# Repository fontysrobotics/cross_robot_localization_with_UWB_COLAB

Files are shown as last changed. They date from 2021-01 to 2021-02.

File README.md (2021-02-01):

# cross_robot_localization_with_UWB_COLAB

The new way to design large scale automation project is through the use of Autonomously Guided Vehicles (AGVs). They allow the connection of different workcells to have more flexibility and all this autonomously. This new technology brings a brandd new market with different companies competing to manufacture the best robot for a said application. This brings the costumers to a place where they have to go to different suppliers for the best AGVs based on their application. Incorporating AGVSs of different brands in the same automation process is a difficult task. While AGVs are good at navigating around a building and completing repetitive tasks, when faced with an unknown moving object such as another AGV they get into trouble. As the different brands cannot communicate this creates a serious issue.

## Project

The goal of the project is to make collaboration between AGVs of different brands possible using a relatively cheap solution. The main issue with collaboration is the lack of communication of crucial data. As the issue arises for navigation, the most important data to be shared between the AGVs is location. Localizing multi-vendor AGVs and sharing their location on the same delocalised system. This will allow the recognition of AGVs as obstacles and will leave room for future implementation of a task division control system. This delocalised communication system will achieve collaboration between the AGVs of various brands.

## Problem

The problem of the assignment is to create a delocalised communication system between the AGVs that can determine the position of each AGV. The localization system is built on the decawave UWB device. The principle of this device is to use the delay in Ultra Wide Band signals to measure distance between the devices on the same network. This localization system must be integrated with the AGVs. Each AGV must have a UWB device for localization which in some way has to be connected to a network of all other AGVs. The creation of this system is the problem of the assignment.

## Solution

In order to incorporate the UWB localization system with the AGV, a device titled Communication and Localization Add on Board or CoLAB was created as a solution. The CoLAB device handles the creation and connection of an AGV to the localization network as well as to the UWB network and the AGV. A CoLAB device is attached to each AGV along with two UWB devices that serve as a front and back tag for the positioning. Inside the CoLAb is a Raspberry pi that reads the positioning information from the two tags via UART. This information is processed to return location and orientation. The CoLAB publishes location, orientation and other useful information from the AGV config file as a message to a network which all AGVs are connected to. From this network AGVs scan and read messages of other AGVs and determine their location orientation and most important properties. This information is sent to the AGV and can be implemented for the software to recognize other AGVs as obstacles. Thus, solving the Communication and Localization issue between AGVs of different vendors. This system also opens the possibility to many more future solutions.

## Navigation of gitHub Page

Within the following the contents of the CoLAB gitHub page will be explained. The three main components the read me, repository and wiki will be highlighted.

* ### Read Me 
Within the read me the basic introduction to the project and problem happens. The products of the project thus to content of the gitHub page is also explained. Alongside this information the main credits to the page as well as a quick how to use guide can be found.

* ### Repository
The repository is where the final products of the project thus the content can be found. This is where the final designs and software can be downloaded from. All the research material used is also provided alongside the datasheets and explaining flow charts and diagrams. Some files to aid with system set up can also be found in the repository.

* ### Wiki
The wiki is where the design is given a further explanation. Each components of the system is given a page along with explanations to its design. Some pages elaborate on the system, validation or final conclusions. For navigation use the table of contents side bar on the right side of the page.

## How to use

Within the following a quick start guide will be given on how to set up the CoLAB system on your own AGV. It is Important to note that this guide will give a global layout and reference set up files, however some extra more in depth set up information might be found in the referenced files.

* ### How to initiate (loading code + connect)
In order to set up a system like the CoLAB first order all the components, print the parts and PCB. After this is completed there is a guide titled (start guide) in the depositor that is an assembly guide to the CoLAB. In this guide further information details how to set up a raspberry pi for the CoLAB as well.
Once the CoLAB is set up it is time to set up the UWB devices with the correct image. Only the tags on the AGV have to be set up

* ### How to set up (config)
It is very easy to use a CoLAB device. It is almost plug and play. There are a couple of things that need to be commpleted before use. A list of these can be found below. It is important to note that these steps must be repeated for each CoLAB device on each AGV.

1. Order all parts and assemble the device compoennets using the [guides](https://github.com/fontysrobotics/cross_robot_localization_with_UWB_COLAB/tree/main/PhysicalSystem/Assembly_documents)
1. Fill out [Configuration File](https://github.com/fontysrobotics/cross_robot_localization_with_UWB_COLAB/blob/main/Software/CoLAB_config.py) of AGV
1. Plug tags to CoLAB and Attach to AGV
1. Note down distance between tags in config file
1. Set up ports of tags using [set up guide](https://github.com/fontysrobotics/cross_robot_localization_with_UWB_COLAB/blob/main/UWB_Documentation/UWB_Setup_Guides/Use%20RaspberryPi%20terminal%20(1).docx)
1. The device must be connected to the network and it is ready to use

* ### End results
As an end reslut of running the code correctly, there are two important aspects taht happen. The communication code between all the connected AGVs is running and they are communicating their information to each other. The second thing is a visualziation software that is built into every AGV. This shows the AGVs around. This is the end result of code in a nutshell, the wiki explains further information of the exact communication and information passing through.

## Bibliography & Credits

This project was created as part of a Mechatronics university course for Fontys University of Applied Sciences with the involvement of the following parties:

### Created by
* Nicole Celine
* Arjan van der Heijden
* Mike Luiken
* Simeon Stoyanov
* Pascal Dinjens
* Long Nguyen
* Ryan Muhammad
* Benedek Papp

### Mentorship and Project Ownership
* Pablo Negrete Rubio
* Sjriek Alers

Throughout the project the following sources were used as guidence, inspiration and technical details:

### Sources

* EEAdi, et al. “Using DWM1001 API on Raspberry Pi and PySerial.” Decawave Tech Forum, 8 Dec. 2019, [decaforum.decawave.com/t/using-dwm1001-api-on-raspberry-pi-and-pyserial/6567]( decaforum.decawave.com/t/using-dwm1001-api-on-raspberry-pi-and-pyserial/6567). 

* Robots, Mobile Industrial. “Please Select Language.” MiR100™ | Mobile Industrial Robots, [www.mobile-industrial-robots.com/en/solutions/robots/mir100/]( www.mobile-industrial-robots.com/en/solutions/robots/mir100/). 

* “The Standard for IoT Messaging.” MQTT, [mqtt.org/]( mqtt.org/).

* Eclipse Mosquitto, 8 Jan. 2018, [mosquitto.org/]( mosquitto.org/.). 

* Craggs, Ian. “Eclipse Paho: The Eclipse Foundation.” Enabling Open Innovation & Collaboration, [www.eclipse.org/paho/]( www.eclipse.org/paho/). 

* “Visualization with Python¶.” Matplotlib, [matplotlib.org/]( matplotlib.org/). 

* “Home.” Decawave, 29 May 2019, [decawave.com/](decawave.com/). 

* Apichet Garaipoom I love the electronic circuits. I will collect a lot of circuit electronics to teach my son and are useful for everyone., et al. “LM2596 Circuit Voltage Regulator and LM2673 Datasheet.” ElecCircuit.com, 19 July 2020, [www.eleccircuit.com/regulator-switching-dc-to-dc-step-down-voltage-with-lm2596/]( www.eleccircuit.com/regulator-switching-dc-to-dc-step-down-voltage-with-lm2596/.). 

* “LTC Debuts LTC4060 NiMH/NiCd Battery Charger - New Industry Products.” EEPower, [eepower.com/new-industry-products/ltc-debuts-ltc4060-nimhnicd-battery-charger/#]( eepower.com/new-industry-products/ltc-debuts-ltc4060-nimhnicd-battery-charger/#). 

* “Dual 4A Ideal Diodes with Adjustable Current Limit.” Datasheet, Linear Technology Co., [datasheet.datasheetarchive.com/originals/distributors/Datasheets-SFU1/DSASFU10008413.pdf]( datasheet.datasheetarchive.com/originals/distributors/Datasheets-SFU1/DSASFU10008413.pdf). 

* Zach-Goh. “Zach-Goh/Omron_LD_ROS_Package.” GitHub, [github.com/zach-goh/Omron_LD_ROS_Package](github.com/zach-goh/Omron_LD_ROS_Package). 

* “OMRON Industrial Automation.” OMRON, [www.ia.omron.com/]( www.ia.omron.com/). 

* “BU-203: Nickel-Based Batteries.” Nickel-Based Batteries Information – Battery University, [batteryuniversity.com/learn/article/nickel_based_batteries](batteryuniversity.com/learn/article/nickel_based_batteries).

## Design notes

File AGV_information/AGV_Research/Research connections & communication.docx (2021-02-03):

# Research Connections & Communication

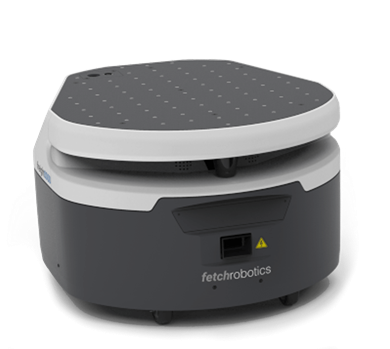
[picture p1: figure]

Fetch Robotics, Freight Base (https://fetchrobotics.com/robotics-platforms/freight-base/)

## Hardware connections wired:

2x USB, 2x Ethernet, RS-45

## Hardware connections wireless:

Wi-Fi: 802.11ABGN and 802.15.1

## Software (operating system):

Ubuntu Linux LTS, Robot Operating System (ROS)

## Control options:

Not specified

# OTTO Motors, OTTO 100 (https://ottomotors.com/amrs)

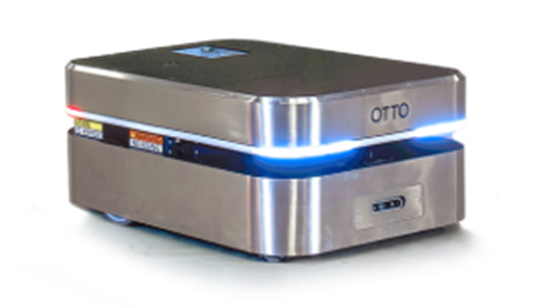
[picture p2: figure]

## Hardware connections wired:

2x USB 3.0, 1x Ethernet POE, 16x DIO, RS-232

## Hardware connections wireless:

Wi-Fi: 802.11ABGNAC, 5 Ghz

## Software (operating system):

Not specified

## Control options:

OTTO Fleet Manager™

OTTO Industrial API

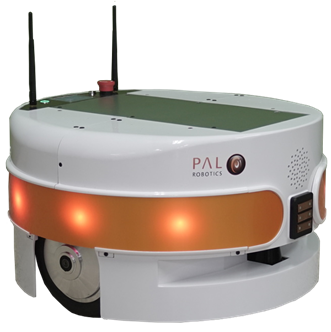
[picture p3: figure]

# PAL Robotics - TIAGo Base (https://pal-robotics.com/robots/tiago-base/)

## Hardware connections wired:

I/O, CAN

## Hardware connections wireless:

Wi-Fi, Bluetooth

## Software (operating system):

Ubuntu LTS, Robot Operating System (ROS) (http://wiki.ros.org/Robots/TIAGo-base)

## Control options:

Web GUI

RESTful API

# Waypoint Robotics, Vector™ (https://waypointrobotics.com/vector-robotic-mobility-platform/)

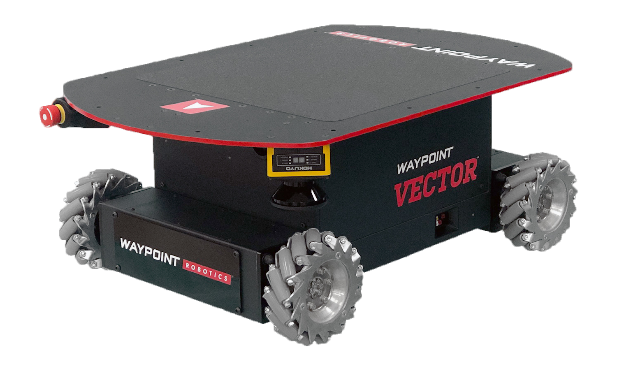
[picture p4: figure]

## Hardware connections wired:

USB, Ethernet

## Hardware connections wireless:

Not specified

## Software (operating system):

Robot Operating System (ROS)

## Control options:

Not specified

## Clearpath, DINGO (https://clearpathrobotics.com/dingo-indoor-mobile-robot/)

## Hardware connections wired:

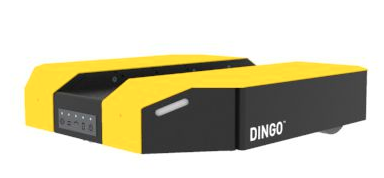
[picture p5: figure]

USB 3.0, Ethernet, RS-232

## Hardware connections wireless:

Not specified

## Software (operating system):

Robot Operating System (ROS)

## Control options:

ROS Kinetic

MoveIt!

ROS ARK API

# Geek+ - M100 (https://www.geekplus.com/product-2/moving)

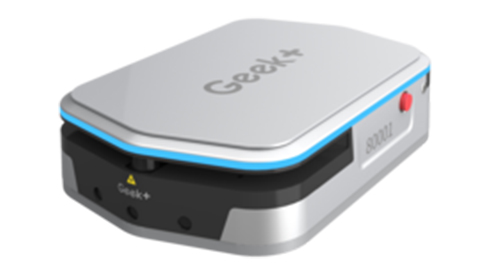
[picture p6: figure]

## Hardware connections wired:

Not specified

## Hardware connections wireless:

Not specified

## Software (operating system):

Not specified

## Control options:

Not specified

Geek+ is only offering complete solutions for warehouse automation. No technical information of the AGVs was found.

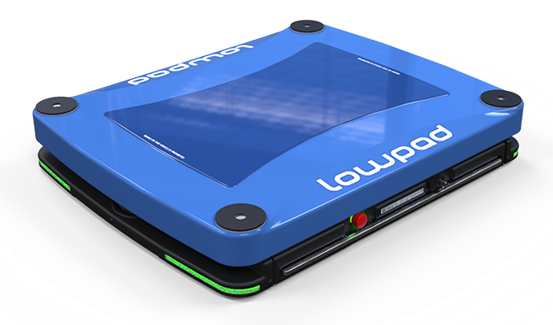
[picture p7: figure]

## Lowpad, M (https://www.lowpad.com/lowpad-family/lowpad-m)

## Hardware connections wired:

?

## Hardware connections wireless:

?

## Software (operating system):

?

## Control options:

?

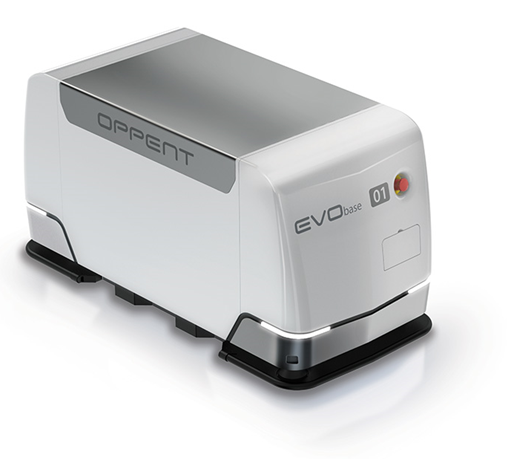
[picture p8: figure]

## Oppent EVO, base™ (https://www.oppent-evo.com/en/prodotto/evo-base-2/)

## Hardware connections wired:

?

## Hardware connections wireless:

?

## Software (operating system):

?

## Control options:

?

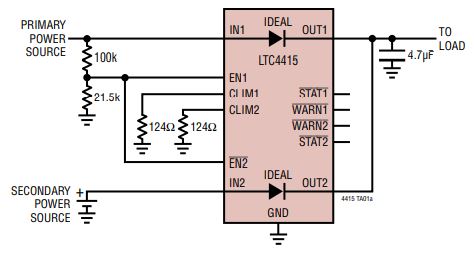
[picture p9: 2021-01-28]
Wiki_Images/LTC4415_Schematic.JPG

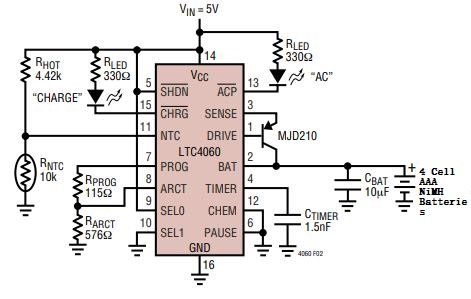
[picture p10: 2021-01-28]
Wiki_Images/LTC4060_Schematic.png

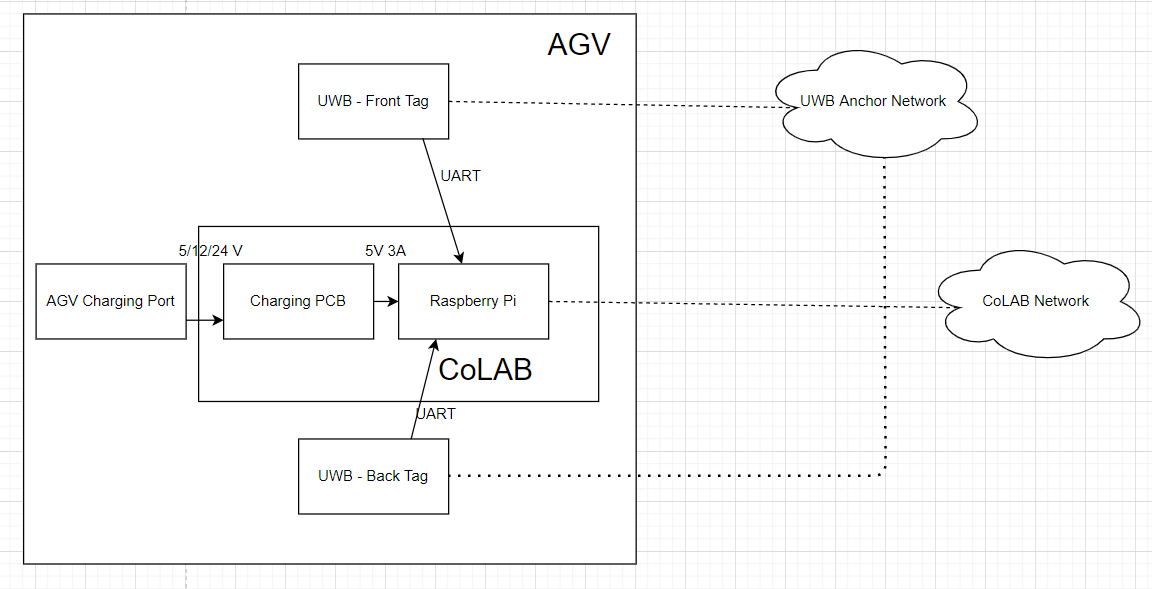
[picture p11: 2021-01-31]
Wiki_Images/System Architecture.PNG

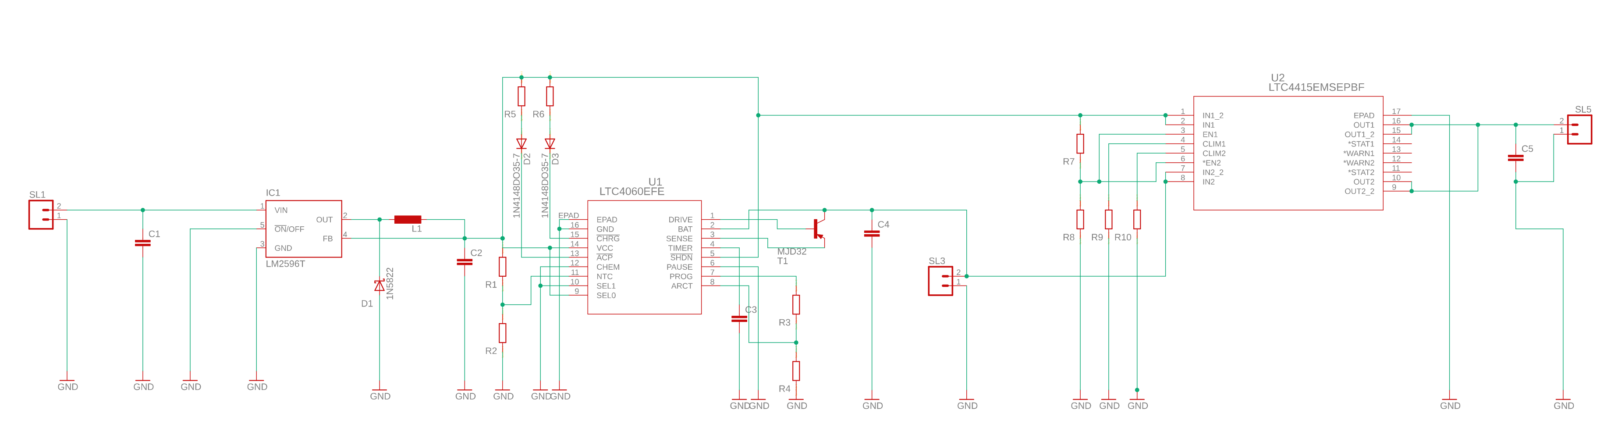
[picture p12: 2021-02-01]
Wiki_Images/MicrosoftTeams-image (1).png

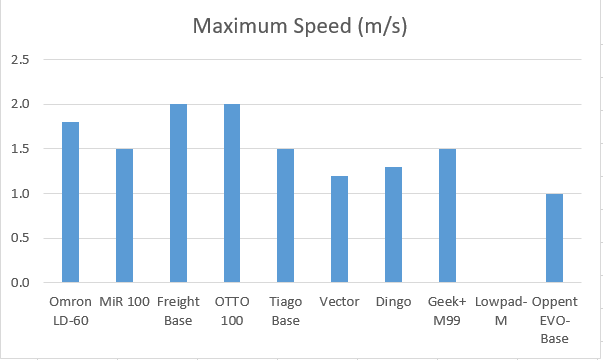
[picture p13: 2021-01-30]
Wiki_Images/AGVinfoMaxSpeed.PNG

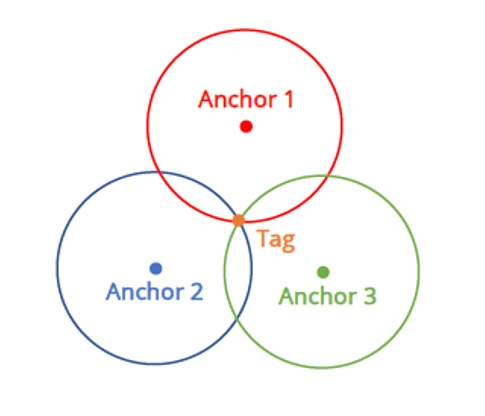
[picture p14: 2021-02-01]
Wiki_Images/pic 2.jpg

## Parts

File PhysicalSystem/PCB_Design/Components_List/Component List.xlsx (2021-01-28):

CoLAB PCB Components List
No. | Components | Description
1 | R NTC (Negative Temperature Components) | 10K
2 | R HOT | 4.42K
3 | R LED | 330
4 | R PROG | 115
5 | R ARCT | 576
6 | MJD210 (PNP) | Complementary Plastic Power Transistor
7 | C TIMER | 1.5nF
8 | C BATTERY | 10µF
9 | LTC4060 | Fast Charging system for NiMH or NiCd batteries
10 | R CLIM1 | 124
11 | R CLIM2 | 124
12 | C OUT (LTC4415) | 4.7µF
13 | R PRIMARY POWER SOURCE (IN 1) | 100K
14 | R PRIMARY POWER SOURCE (EN 1) | 21.5K
15 | LTC4415 | Two monolithic PowerPath ideal diodes
16 | C IN | 680µF
17 | 1N5822 | 3.0 Amps Schottky Barrier Rectifiers
18 | COIL | 33 µH

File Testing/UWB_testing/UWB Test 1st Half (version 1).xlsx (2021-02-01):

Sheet: MiRtest1
Time Stamp | Tag identifier | Column3 | Column4.1.1 | X | Y | Z | Q | Column4.2 | Column5.1 | Column5.2 | Column5.3 | Column5.4 | Column5.5 | Column5.6 | Column5.7 | Column5.8 | Column5.9 | Column5.10 | Column5.11 | Column5.12 | Column5.13 | Column6 | Column7
1602569 | started location data observation of FF | F9 | 57 |  |  |  |  |  | 8C |  |  |  |  |  |  |  |  |  |  |  |  | C7 | 34
1602616 | 0xâ€¦4583 location data | position |  | 1679 | 811 | 220 | 29 | distances |  | 5486 | distance=Distance{length=2941, | 100 | 8397 | distance=Distance{length=8418, | 100 | 0C0C | distance=Distance{length=9623, | 100 | 1B06 | distance=Distance{length=12305, | 100}
1602617 | 0xâ€¦4583 location data | position |  | 1679 | 828 | 231 | 31 | distances |  | 5486 | distance=Distance{length=2941, | 100 | 8397 | distance=Distance{length=8357, | 100 | 0C0C | distance=Distance{length=9543, | 100 | 1B06 | distance=Distance{length=12286, | 100}
1602717 | 0xâ€¦4583 location data | position |  | 1675 | 826 | 230 | 30 | distances |  | 5486 | distance=Distance{length=2922, | 100 | 8397 | distance=Distance{length=8409, | 100 | 0C0C | distance=Distance{length=9599, | 100 | 1B06 | distance=Distance{length=12295, | 100}
1602816 | 0xâ€¦4583 location data | position |  | 1685 | 805 | 235 | 33 | distances |  | 5486 | distance=Distance{length=2913, | 100 | 8397 | distance=Distance{length=8343, | 100 | 0C0C | distance=Distance{length=9674, | 100 | 1B06 | distance=Distance{length=12319, | 100}
1602916 | 0xâ€¦4583 location data | position |  | 1665 | 790 | 241 | 30 | distances |  | 5486 | distance=Distance{length=2857, | 100 | 8397 | distance=Distance{length=8432, | 100 | 0C0C | distance=Distance{length=9656, | 100 | 1B06 | distance=Distance{length=12262, | 100}
1603017 | 0xâ€¦4583 location data | position |  | 1656 | 791 | 232 | 29 | distances |  | 5486 | distance=Distance{length=2908, | 100 | 8397 | distance=Distance{length=8451, | 100 | 0C0C | distance=Distance{length=9623, | 100 | 1B06 | distance=Distance{length=12319, | 100}
1603082 | 0xâ€¦4583 location data | position |  | 1649 | 788 | 242 | 31 | distances |  | 5486 | distance=Distance{length=2866, | 100 | 8397 | distance=Distance{length=8409, | 100 | 0C0C | distance=Distance{length=9623, | 100 | 1B06 | distance=Distance{length=12459, | 100}
1603181 | 0xâ€¦4583 location data | position |  | 1659 | 784 | 234 | 31 | distances |  | 5486 | distance=Distance{length=2951, | 100 | 8397 | distance=Distance{length=8366, | 100 | 0C0C | distance=Distance{length=9656, | 100 | 1B06 | distance=Distance{length=12239, | 100}
1603215 | 0xâ€¦5106 location data | position |  | 2153 | 744 | -138 | 30 | distances |  | 5486 | distance=Distance{length=3489, | 100 | 8397 | distance=Distance{length=8034, | 100 | 0C0C | distance=Distance{length=9848, | 100}
1603234 | started location data observation of D4 | F1 | 18 |  |  |  |  |  | F0 |  |  |  |  |  |  |  |  |  |  |  |  | 24 | 55
1603281 | 0xâ€¦4583 location data | position |  | 1657 | 789 | 223 | 29 | distances |  | 5486 | distance=Distance{length=2951, | 100 | 8397 | distance=Distance{length=8409, | 100 | 0C0C | distance=Distance{length=9623, | 100 | 1B06 | distance=Distance{length=12342, | 100}
1603315 | 0xâ€¦5106 location data | position |  | 2154 | 745 | -138 | 31 | distances |  | 5486 | distance=Distance{length=3489, | 100 | 8397 | distance=Distance{length=8025, | 100 | 0C0C | distance=Distance{length=9857, | 100 | 1B06 | distance=Distance{length=11929, | 100}
1603382 | 0xâ€¦5106 location data | position |  | 2174 | 737 | -125 | 34 | distances |  | 5486 | distance=Distance{length=3489, | 100 | 8397 | distance=Distance{length=7936, | 100 | 0C0C | distance=Distance{length=9895, | 100 | 1B06 | distance=Distance{length=11962, | 100}
1603382 | 0xâ€¦4583 location data | position |  | 1650 | 782 | 228 | 30 | distances |  | 5486 | distance=Distance{length=2866, | 100 | 8397 | distance=Distance{length=8451, | 100 | 0C0C | distance=Distance{length=9642, | 100 | 1B06 | distance=Distance{length=12319, | 100}
1603483 | 0xâ€¦5106 location data | position |  | 2176 | 733 | -116 | 33 | distances |  | 5486 | distance=Distance{length=3461, | 100 | 8397 | distance=Distance{length=7982, | 100 | 0C0C | distance=Distance{length=9876, | 100 | 1B06 | distance=Distance{length=11972, | 100}
1603501 | 0xâ€¦4583 location data | position |  | 1648 | 796 | 225 | 29 | distances |  | 5486 | distance=Distance{length=2955, | 100 | 8397 | distance=Distance{length=8381, | 100 | 0C0C | distance=Distance{length=9590, | 100 | 1B06 | distance=Distance{length=12375, | 100}
1603582 | 0xâ€¦5106 location data | position |  | 2175 | 732 | -113 | 32 | distances |  | 5486 | distance=Distance{length=3471, | 100 | 8397 | distance=Distance{length=7997, | 100 | 0C0C | distance=Distance{length=9871, | 100 | 1B06 | distance=Distance{length=11859, | 100}
1603583 | 0xâ€¦4583 location data | position |  | 1654 | 799 | 206 | 28 | distances |  | 5486 | distance=Distance{length=3002, | 100 | 8397 | distance=Distance{length=8390, | 100 | 0C0C | distance=Distance{length=9637, | 100 | 1B06 | distance=Distance{length=12342, | 100}
1603682 | 0xâ€¦5106 location data | position |  | 2192 | 731 | -103 | 34 | distances |  | 5486 | distance=Distance{length=3489, | 100 | 8397 | distance=Distance{length=7922, | 100 | 0C0C | distance=Distance{length=9881, | 100 | 1B06 | distance=Distance{length=11887, | 100}
1603683 | 0xâ€¦4583 location data | position |  | 1667 | 797 | 177 | 28 | distances |  | 5486 | distance=Distance{length=3044, | 100 | 8397 | distance=Distance{length=8409, | 100 | 0C0C | distance=Distance{length=9665, | 100 | 1B06 | distance=Distance{length=12286, | 100}
1603782 | 0xâ€¦5106 location data | position |  | 2190 | 723 | -106 | 32 | distances |  | 5486 | distance=Distance{length=3480, | 100 | 8397 | distance=Distance{length=7987, | 100 | 0C0C | distance=Distance{length=9904, | 100 | 1B06 | distance=Distance{length=11901, | 100}
1603799 | 0xâ€¦4583 location data | position |  | 1664 | 809 | 211 | 32 | distances |  | 5486 | distance=Distance{length=2880, | 100 | 8397 | distance=Distance{length=8362, | 100 | 0C0C | distance=Distance{length=9557, | 100 | 1B06 | distance=Distance{length=12305, | 100}
1603881 | 0xâ€¦5106 location data | position |  | 2188 | 718 | -108 | 32 | distances |  | 5486 | distance=Distance{length=3475, | 100 | 8397 | distance=Distance{length=7992, | 100 | 0C0C | distance=Distance{length=9900, | 100 | 1B06 | distance=Distance{length=11840, | 100}
1603882 | 0xâ€¦4583 location data | position |  | 1660 | 821 | 192 | 27 | distances |  | 5486 | distance=Distance{length=3012, | 100 | 8397 | distance=Distance{length=8423, | 100 | 0C0C | distance=Distance{length=9590, | 100 | 1B06 | distance=Distance{length=12328, | 100}
1603983 | 0xâ€¦5106 location data | position |  | 2195 | 732 | -98 | 33 | distances |  | 5486 | distance=Distance{length=3480, | 100 | 8397 | distance=Distance{length=7950, | 100 | 0C0C | distance=Distance{length=9829, | 100 | 1B06 | distance=Distance{length=11864, | 100}
1603985 | 0xâ€¦4583 location data | position |  | 1676 | 822 | 181 | 29 | distances |  | 5486 | distance=Distance{length=3040, | 100 | 8397 | distance=Distance{length=8343, | 100 | 0C0C | distance=Distance{length=9628, | 100 | 1B06 | distance=Distance{length=12290, | 100}
1604081 | 0xâ€¦5106 location data | position |  | 2192 | 746 | -100 | 32 | distances |  | 5486 | distance=Distance{length=3489, | 100 | 8397 | distance=Distance{length=7992, | 100 | 0C0C | distance=Distance{length=9820, | 100 | 1B06 | distance=Distance{length=11901, | 100}
1604099 | 0xâ€¦4583 location data | position |  | 1662 | 801 | 191 | 30 | distances |  | 5486 | distance=Distance{length=2890, | 100 | 8397 | distance=Distance{length=8427, | 100 | 0C0C | distance=Distance{length=9674, | 100 | 1B06 | distance=Distance{length=12295, | 100}
1604181 | 0xâ€¦5106 location data | position |  | 2189 | 734 | -110 | 31 | distances |  | 5486 | distance=Distance{length=3494, | 100 | 8397 | distance=Distance{length=8001, | 100 | 0C0C | distance=Distance{length=9909, | 100 | 1B06 | distance=Distance{length=11873, | 100}
1604182 | 0xâ€¦4583 location data | position |  | 1666 | 805 | 198 | 30 | distances |  | 5486 | distance=Distance{length=2937, | 100 | 8397 | distance=Distance{length=8399, | 100 | 0C0C | distance=Distance{length=9604, | 100 | 1B06 | distance=Distance{length=12286, | 100}
1604282 | 0xâ€¦4583 location data | position |  | 1667 | 809 | 206 | 30 | distances |  | 5486 | distance=Distance{length=2937, | 100 | 8397 | distance=Distance{length=8376, | 100 | 0C0C | distance=Distance{length=9604, | 100 | 1B06 | distance=Distance{length=12319, | 100}
1604299 | 0xâ€¦5106 location data | position |  | 2199 | 746 | -109 | 33 | distances |  | 5486 | distance=Distance{length=3518, | 100 | 8397 | distance=Distance{length=7950, | 100 | 0C0C | distance=Distance{length=9834, | 100 | 1B06 | distance=Distance{length=11887, | 100}
1604383 | 0xâ€¦5106 location data | position |  | 2178 | 748 | -126 | 29 | distances |  | 5486 | distance=Distance{length=3494, | 100 | 8397 | distance=Distance{length=8076, | 100 | 0C0C | distance=Distance{length=9857, | 100 | 1B06 | distance=Distance{length=11943, | 100}
1604400 | 0xâ€¦4583 location data | position |  | 1662 | 804 | 229 | 32 | distances |  | 5486 | distance=Distance{length=2862, | 100 | 8397 | distance=Distance{length=8385, | 100 | 0C0C | distance=Distance{length=9609, | 100 | 1B06 | distance=Distance{length=12234, | 100}
1604481 | 0xâ€¦5106 location data | position |  | 2171 | 735 | -123 | 32 | distances |  | 5486 | distance=Distance{length=3457, | 100 | 8397 | distance=Distance{length=8020, | 100 | 0C0C | distance=Distance{length=9900, | 100 | 1B06 | distance=Distance{length=11854, | 100}
1604482 | 0xâ€¦4583 location data | position |  | 1662 | 796 | 235 | 31 | distances |  | 5486 | distance=Distance{length=2880, | 100 | 8397 | distance=Distance{length=8413, | 100 | 0C0C | distance=Distance{length=9637, | 100 | 1B06 | distance=Distance{length=12290, | 100}
1604598 | 0xâ€¦5106 location data | position |  | 2168 | 733 | -126 | 31 | distances |  | 5486 | distance=Distance{length=3485, | 100 | 8397 | distance=Distance{length=8020, | 100 | 0C0C | distance=Distance{length=9876, | 100 | 1B06 | distance=Distance{length=11892, | 100}
1604600 | 0xâ€¦4583 location data | position |  | 1666 | 803 | 236 | 31 | distances |  | 5486 | distance=Distance{length=2932, | 100 | 8397 | distance=Distance{length=8376, | 100 | 0C0C | distance=Distance{length=9595, | 100 | 1B06 | distance=Distance{length=12295, | 100}
1604681 | 0xâ€¦5106 location data | position |  | 2169 | 737 | -117 | 32 | distances |  | 5486 | distance=Distance{length=3461, | 100 | 8397 | distance=Distance{length=7997, | 100 | 0C0C | distance=Distance{length=9848, | 100 | 1B06 | distance=Distance{length=11920, | 100}
1604699 | 0xâ€¦4583 location data | position |  | 1672 | 798 | 245 | 32 | distances |  | 5486 | distance=Distance{length=2890, | 100 | 8397 | distance=Distance{length=8371, | 100 | 0C0C | distance=Distance{length=9628, | 100 | 1B06 | distance=Distance{length=12300, | 100}
1604781 | 0xâ€¦5106 location data | position |  | 2161 | 742 | -124 | 30 | distances |  | 5486 | distance=Distance{length=3485, | 100 | 8397 | distance=Distance{length=8048, | 100 | 0C0C | distance=Distance{length=9848, | 100 | 1B06 | distance=Distance{length=11868, | 100}
1604782 | 0xâ€¦4583 location data | position |  | 1680 | 805 | 236 | 58 | distances |  | 5486 | distance=Distance{length=2974, | 100 | 8397 | distance=Distance{length=8357, | 100 | 1B06 | distance=Distance{length=12286, | 100}
1604881 | 0xâ€¦5106 location data | position |  | 2165 | 743 | -121 | 32 | distances |  | 5486 | distance=Distance{length=3480, | 100 | 8397 | distance=Distance{length=7997, | 100 | 0C0C | distance=Distance{length=9857, | 100 | 1B06 | distance=Distance{length=11859, | 100}
1604883 | 0xâ€¦4583 location data | position |  | 1686 | 814 | 233 | 31 | distances |  | 5486 | distance=Distance{length=2983, | 100 | 8397 | distance=Distance{length=8324, | 100 | 0C0C | distance=Distance{length=9595, | 100 | 1B06 | distance=Distance{length=12328, | 100}
1604982 | 0xâ€¦5106 location data | position |  | 2167 | 738 | -120 | 32 | distances |  | 5486 | distance=Distance{length=3480, | 100 | 8397 | distance=Distance{length=8001, | 100 | 0C0C | distance=Distance{length=9881, | 100 | 1B06 | distance=Distance{length=11901, | 100}
1604999 | 0xâ€¦4583 location data | position |  | 1688 | 811 | 192 | 27 | distances |  | 5486 | distance=Distance{length=3054, | 100 | 8397 | distance=Distance{length=8427, | 100 | 0C0C | distance=Distance{length=9656, | 100 | 1B06 | distance=Distance{length=12286, | 100}
1605081 | 0xâ€¦5106 location data | position |  | 2169 | 752 | -123 | 31 | distances |  | 5486 | distance=Distance{length=3503, | 100 | 8397 | distance=Distance{length=8011, | 100 | 0C0C | distance=Distance{length=9820, | 100 | 1B06 | distance=Distance{length=11864, | 100}
1605082 | 0xâ€¦4583 location data | position |  | 1693 | 803 | 211 | 33 | distances |  | 5486 | distance=Distance{length=2904, | 100 | 8397 | distance=Distance{length=8352, | 100 | 0C0C | distance=Distance{length=9637, | 100 | 1B06 | distance=Distance{length=12290, | 100}
1605181 | 0xâ€¦5106 location data | position |  | 2170 | 751 | -127 | 31 | distances |  | 5486 | distance=Distance{length=3499, | 100 | 8397 | distance=Distance{length=8011, | 100 | 0C0C | distance=Distance{length=9862, | 100 | 1B06 | distance=Distance{length=11854, | 100}
1605199 | 0xâ€¦4583 location data | position |  | 1695 | 799 | 229 | 33 | distances |  | 5486 | distance=Distance{length=2894, | 100 | 8397 | distance=Distance{length=8352, | 100 | 0C0C | distance=Distance{length=9623, | 100 | 1B06 | distance=Distance{length=12286, | 100}
1605282 | 0xâ€¦5106 location data | position |  | 2176 | 756 | -114 | 33 | distances |  | 5486 | distance=Distance{length=3471, | 100 | 8397 | distance=Distance{length=7973, | 100 | 0C0C | distance=Distance{length=9829, | 100 | 1B06 | distance=Distance{length=11915, | 100}
1605299 | 0xâ€¦4583 location data | position |  | 1681 | 816 | 211 | 27 | distances |  | 5486 | distance=Distance{length=2974, | 100 | 8397 | distance=Distance{length=8460, | 100 | 0C0C | distance=Distance{length=9567, | 100 | 1B06 | distance=Distance{length=12286, | 100}
1605373 | 0xâ€¦5106 location data | position |  | 2160 | 744 | -112 | 31 | distances |  | 5486 | distance=Distance{length=3428, | 100 | 8397 | distance=Distance{length=8053, | 100 | 0C0C | distance=Distance{length=9876, | 100 | 1B06 | distance=Distance{length=11906, | 100}
1605390 | 0xâ€¦4583 location data | position |  | 1686 | 816 | 188 | 28 | distances |  | 5486 | distance=Distance{length=3026, | 100 | 8397 | distance=Distance{length=8404, | 100 | 0C0C | distance=Distance{length=9632, | 100 | 1B06 | distance=Distance{length=12272, | 100}
1605489 | 0xâ€¦4583 location data | position |  | 1673 | 830 | 202 | 29 | distances |  | 5486 | distance=Distance{length=2927, | 100 | 8397 | distance=Distance{length=8404, | 100 | 0C0C | distance=Distance{length=9548, | 100 | 1B06 | distance=Distance{length=12309, | 100}
1605507 | 0xâ€¦5106 location data | position |  | 2165 | 735 | -115 | 32 | distances |  | 5486 | distance=Distance{length=3485, | 100 | 8397 | distance=Distance{length=7997, | 100 | 0C0C | distance=Distance{length=9900, | 100 | 1B06 | distance=Distance{length=11873, | 100}
1605572 | 0xâ€¦5106 location data | position |  | 2158 | 720 | -120 | 31 | distances |  | 5486 | distance=Distance{length=3461, | 100 | 8397 | distance=Distance{length=8034, | 100 | 0C0C | distance=Distance{length=9923, | 100 | 1B06 | distance=Distance{length=11873, | 100}
1605590 | 0xâ€¦4583 location data | position |  | 1673 | 835 | 200 | 29 | distances |  | 5486 | distance=Distance{length=2983, | 100 | 8397 | distance=Distance{length=8376, | 100 | 0C0C | distance=Distance{length=9585, | 100 | 1B06 | distance=Distance{length=12323, | 100}
1605672 | 0xâ€¦5106 location data | position |  | 2157 | 721 | -127 | 31 | distances |  | 5486 | distance=Distance{length=3489, | 100 | 8397 | distance=Distance{length=8029, | 100 | 0C0C | distance=Distance{length=9881, | 100 | 1B06 | distance=Distance{length=11934, | 100}
1605689 | 0xâ€¦4583 location data | position |  | 1657 | 836 | 206 | 29 | distances |  | 5486 | distance=Distance{length=2922, | 100 | 8397 | distance=Distance{length=8427, | 100 | 0C0C | distance=Distance{length=9576, | 100 | 1B06 | distance=Distance{length=12351, | 100}
1605772 | 0xâ€¦5106 location data | position |  | 2152 | 720 | -135 | 30 | distances |  | 5486 | distance=Distance{length=3485, | 100 | 8397 | distance=Distance{length=8048, | 100 | 0C0C | distance=Distance{length=9890, | 100 | 1B06 | distance=Distance{length=11864, | 100}
1605789 | 0xâ€¦4583 location data | position |  | 1650 | 821 | 223 | 31 | distances |  | 5486 | distance=Distance{length=2871, | 100 | 8397 | distance=Distance{length=8399, | 100 | 0C0C | distance=Distance{length=9628, | 100 | 1B06 | distance=Distance{length=12370, | 100}
1605889 | 0xâ€¦4583 location data | position |  | 1650 | 798 | 223 | 31 | distances |  | 5486 | distance=Distance{length=2885, | 100 | 8397 | distance=Distance{length=8427, | 100 | 0C0C | distance=Distance{length=9684, | 100 | 1B06 | distance=Distance{length=12347, | 100}
1605890 | 0xâ€¦5106 location data | position |  | 2161 | 727 | -131 | 32 | distances |  | 5486 | distance=Distance{length=3494, | 100 | 8397 | distance=Distance{length=7992, | 100 | 0C0C | distance=Distance{length=9862, | 100 | 1B06 | distance=Distance{length=11901, | 100}
1605972 | 0xâ€¦5106 location data | position |  | 2170 | 730 | -116 | 33 | distances |  | 5486 | distance=Distance{length=3461, | 100 | 8397 | distance=Distance{length=7964, | 100 | 0C0C | distance=Distance{length=9857, | 100 | 1B06 | distance=Distance{length=11882, | 100}
1605989 | 0xâ€¦4583 location data | position |  | 1663 | 800 | 237 | 33 | distances |  | 5486 | distance=Distance{length=2913, | 100 | 8397 | distance=Distance{length=8338, | 100 | 0C0C | distance=Distance{length=9609, | 100 | 1B06 | distance=Distance{length=12408, | 100}
1606072 | 0xâ€¦5106 location data | position |  | 2168 | 732 | -123 | 31 | distances |  | 5486 | distance=Distance{length=3494, | 100 | 8397 | distance=Distance{length=8020, | 100 | 0C0C | distance=Distance{length=9871, | 100 | 1B06 | distance=Distance{length=11896, | 100}
1606089 | 0xâ€¦4583 location data | position |  | 1666 | 806 | 250 | 32 | distances |  | 5486 | distance=Distance{length=2885, | 100 | 8397 | distance=Distance{length=8376, | 100 | 0C0C | distance=Distance{length=9581, | 100 | 1B06 | distance=Distance{length=12281, | 100}
1606172 | 0xâ€¦5106 location data | position |  | 2174 | 745 | -115 | 32 | distances |  | 5486 | distance=Distance{length=3485, | 100 | 8397 | distance=Distance{length=7982, | 100 | 0C0C | distance=Distance{length=9820, | 100 | 1B06 | distance=Distance{length=11873, | 100}
1606190 | 0xâ€¦4583 location data | position |  | 1671 | 798 | 218 | 28 | distances |  | 5486 | distance=Distance{length=3021, | 100 | 8397 | distance=Distance{length=8385, | 100 | 0C0C | distance=Distance{length=9679, | 100 | 1B06 | distance=Distance{length=12356, | 100}
1606272 | 0xâ€¦5106 location data | position |  | 2184 | 736 | -108 | 33 | distances |  | 5486 | distance=Distance{length=3480, | 100 | 8397 | distance=Distance{length=7950, | 100 | 0C0C | distance=Distance{length=9895, | 100 | 1B06 | distance=Distance{length=11906, | 100}
1606289 | 0xâ€¦4583 location data | position |  | 1682 | 781 | 222 | 32 | distances |  | 5486 | distance=Distance{length=2918, | 100 | 8397 | distance=Distance{length=8357, | 100 | 0C0C | distance=Distance{length=9689, | 100 | 1B06 | distance=Distance{length=12305, | 100}
1606372 | 0xâ€¦5106 location data | position |  | 2188 | 733 | -111 | 32 | distances |  | 5486 | distance=Distance{length=3494, | 100 | 8397 | distance=Distance{length=7978, | 100 | 0C0C | distance=Distance{length=9886, | 100 | 1B06 | distance=Distance{length=11901, | 100}
1606390 | 0xâ€¦4583 location data | position |  | 1694 | 789 | 198 | 29 | distances |  | 5486 | distance=Distance{length=3063, | 100 | 8397 | distance=Distance{length=8329, | 100 | 0C0C | distance=Distance{length=9651, | 100 | 1B06 | distance=Distance{length=12333, | 100}
1606481 | 0xâ€¦5106 location data | position |  | 2184 | 743 | -105 | 32 | distances |  | 5486 | distance=Distance{length=3466, | 100 | 8397 | distance=Distance{length=7997, | 100 | 0C0C | distance=Distance{length=9825, | 100 | 1B06 | distance=Distance{length=11831, | 100}
1606498 | 0xâ€¦4583 location data | position |  | 1681 | 797 | 216 | 31 | distances |  | 5486 | distance=Distance{length=2876, | 100 | 8397 | distance=Distance{length=8418, | 100 | 0C0C | distance=Distance{length=9581, | 100 | 1B06 | distance=Distance{length=12300, | 100}
1606581 | 0xâ€¦5106 location data | position |  | 2183 | 737 | -106 | 32 | distances |  | 5486 | distance=Distance{length=3475, | 100 | 8397 | distance=Distance{length=7992, | 100 | 0C0C | distance=Distance{length=9886, | 100 | 1B06 | distance=Distance{length=11882, | 100}
1606582 | 0xâ€¦4583 location data | position |  | 1668 | 809 | 239 | 31 | distances |  | 5486 | distance=Distance{length=2871, | 100 | 8397 | distance=Distance{length=8385, | 100 | 0C0C | distance=Distance{length=9557, | 100 | 1B06 | distance=Distance{length=12333, | 100}
1606698 | 0xâ€¦4583 location data | position |  | 1682 | 800 | 229 | 31 | distances |  | 5486 | distance=Distance{length=2969, | 100 | 8397 | distance=Distance{length=8348, | 100 | 0C0C | distance=Distance{length=9660, | 100 | 1B06 | distance=Distance{length=12295, | 100}
1606699 | 0xâ€¦5106 location data | position |  | 2184 | 742 | -96 | 33 | distances |  | 5486 | distance=Distance{length=3457, | 100 | 8397 | distance=Distance{length=7973, | 100 | 0C0C | distance=Distance{length=9839, | 100 | 1B06 | distance=Distance{length=11939, | 100}
1606781 | 0xâ€¦5106 location data | position |  | 2178 | 753 | -94 | 32 | distances |  | 5486 | distance=Distance{length=3461, | 100 | 8397 | distance=Distance{length=8011, | 100 | 0C0C | distance=Distance{length=9810, | 100 | 1B06 | distance=Distance{length=11859, | 100}
1606798 | 0xâ€¦4583 location data | position |  | 1680 | 805 | 237 | 31 | distances |  | 5486 | distance=Distance{length=2922, | 100 | 8397 | distance=Distance{length=8357, | 100 | 0C0C | distance=Distance{length=9599, | 100 | 1B06 | distance=Distance{length=12333, | 100}
1606880 | 0xâ€¦5106 location data | position |  | 2172 | 755 | -95 | 32 | distances |  | 5486 | distance=Distance{length=3461, | 100 | 8397 | distance=Distance{length=8015, | 100 | 0C0C | distance=Distance{length=9834, | 100 | 1B06 | distance=Distance{length=11892, | 100}
1606881 | 0xâ€¦4583 location data | position |  | 1683 | 797 | 245 | 32 | distances |  | 5486 | distance=Distance{length=2908, | 100 | 8397 | distance=Distance{length=8338, | 100 | 0C0C | distance=Distance{length=9642, | 100 | 1B06 | distance=Distance{length=12333, | 100}
1606982 | 0xâ€¦5106 location data | position |  | 2165 | 754 | -102 | 31 | distances |  | 5486 | distance=Distance{length=3471, | 100 | 8397 | distance=Distance{length=8034, | 100 | 0C0C | distance=Distance{length=9848, | 100 | 1B06 | distance=Distance{length=11892, | 100}
1606983 | 0xâ€¦4583 location data | position |  | 1674 | 796 | 261 | 32 | distances |  | 5486 | distance=Distance{length=2857, | 100 | 8397 | distance=Distance{length=8376, | 100 | 0C0C | distance=Distance{length=9609, | 100 | 1B06 | distance=Distance{length=12342, | 100}
1607080 | 0xâ€¦5106 location data | position |  | 2167 | 746 | -106 | 32 | distances |  | 5486 | distance=Distance{length=3475, | 100 | 8397 | distance=Distance{length=8001, | 100 | 0C0C | distance=Distance{length=9881, | 100 | 1B06 | distance=Distance{length=11835, | 100}
1607098 | 0xâ€¦4583 location data | position |  | 1654 | 803 | 246 | 28 | distances |  | 5486 | distance=Distance{length=2918, | 100 | 8397 | distance=Distance{length=8465, | 100 | 0C0C | distance=Distance{length=9590, | 100 | 1B06 | distance=Distance{length=12225, | 100}
1607180 | 0xâ€¦5106 location data | position |  | 2186 | 758 | -92 | 34 | distances |  | 5486 | distance=Distance{length=3471, | 100 | 8397 | distance=Distance{length=7945, | 100 | 0C0C | distance=Distance{length=9806, | 100 | 1B06 | distance=Distance{length=11976, | 100}
1607181 | 0xâ€¦4583 location data | position |  | 1662 | 800 | 232 | 30 | distances |  | 5486 | distance=Distance{length=2946, | 100 | 8397 | distance=Distance{length=8409, | 100 | 0C0C | distance=Distance{length=9637, | 100 | 1B06 | distance=Distance{length=12276, | 100}
1607280 | 0xâ€¦5106 location data | position |  | 2184 | 767 | -89 | 32 | distances |  | 5486 | distance=Distance{length=3471, | 100 | 8397 | distance=Distance{length=7992, | 100 | 0C0C | distance=Distance{length=9806, | 100 | 1B06 | distance=Distance{length=11934, | 100}
1607298 | 0xâ€¦4583 location data | position |  | 1670 | 811 | 243 | 32 | distances |  | 5486 | distance=Distance{length=2904, | 100 | 8397 | distance=Distance{length=8381, | 100 | 0C0C | distance=Distance{length=9567, | 100 | 1B06 | distance=Distance{length=12220, | 100}
1607380 | 0xâ€¦5106 location data | position |  | 2176 | 752 | -105 | 31 | distances |  | 5486 | distance=Distance{length=3489, | 100 | 8397 | distance=Distance{length=8029, | 100 | 0C0C | distance=Distance{length=9900, | 100 | 1B06 | distance=Distance{length=11845, | 100}
1607398 | 0xâ€¦4583 location data | position |  | 1673 | 816 | 228 | 29 | distances |  | 5486 | distance=Distance{length=2983, | 100 | 8397 | distance=Distance{length=8381, | 100 | 0C0C | distance=Distance{length=9604, | 100 | 1B06 | distance=Distance{length=12300, | 100}
1607480 | 0xâ€¦5106 location data | position |  | 2170 | 737 | -103 | 32 | distances |  | 5486 | distance=Distance{length=3442, | 100 | 8397 | distance=Distance{length=8011, | 100 | 0C0C | distance=Distance{length=9900, | 100 | 1B06 | distance=Distance{length=11892, | 100}
1607481 | 0xâ€¦4583 location data | position |  | 1673 | 825 | 219 | 29 | distances |  | 5486 | distance=Distance{length=2974, | 100 | 8397 | distance=Distance{length=8395, | 100 | 0C0C | distance=Distance{length=9581, | 100}
1607581 | 0xâ€¦5106 location data | position |  | 2165 | 733 | -104 | 32 | distances |  | 5486 | distance=Distance{length=3457, | 100 | 8397 | distance=Distance{length=8020, | 100 | 0C0C | distance=Distance{length=9876, | 100 | 1B06 | distance=Distance{length=11925, | 100}
1607598 | 0xâ€¦4583 location data | position |  | 1676 | 812 | 218 | 31 | distances |  | 5486 | distance=Distance{length=2932, | 100 | 8397 | distance=Distance{length=8385, | 100 | 0C0C | distance=Distance{length=9651, | 100 | 1B06 | distance=Distance{length=12323, | 100}
1607680 | 0xâ€¦5106 location data | position |  | 2162 | 716 | -116 | 31 | distances |  | 5486 | distance=Distance{length=3480, | 100 | 8397 | distance=Distance{length=8025, | 100 | 0C0C | distance=Distance{length=9937, | 100 | 1B06 | distance=Distance{length=11859, | 100}
1607698 | 0xâ€¦4583 location data | position |  | 1670 | 819 | 209 | 28 | distances |  | 5486 | distance=Distance{length=2979, | 100 | 8397 | distance=Distance{length=8399, | 100 | 0C0C | distance=Distance{length=9595, | 100 | 1B06 | distance=Distance{length=12342, | 100}
1607780 | 0xâ€¦5106 location data | position |  | 2155 | 723 | -115 | 31 | distances |  | 5486 | distance=Distance{length=3452, | 100 | 8397 | distance=Distance{length=8039, | 100 | 0C0C | distance=Distance{length=9853, | 100 | 1B06 | distance=Distance{length=11906, | 100}
1607781 | 0xâ€¦4583 location data | position |  | 1664 | 815 | 213 | 30 | distances |  | 5486 | distance=Distance{length=2937, | 100 | 8397 | distance=Distance{length=8376, | 100 | 0C0C | distance=Distance{length=9618, | 100 | 1B06 | distance=Distance{length=12389, | 100}
1607880 | 0xâ€¦5106 location data | position |  | 2155 | 717 | -116 | 32 | distances |  | 5486 | distance=Distance{length=3466, | 100 | 8397 | distance=Distance{length=8015, | 100 | 0C0C | distance=Distance{length=9900, | 100 | 1B06 | distance=Distance{length=11873, | 100}
1607898 | 0xâ€¦4583 location data | position |  | 1666 | 822 | 225 | 31 | distances |  | 5486 | distance=Distance{length=2918, | 100 | 8397 | distance=Distance{length=8376, | 100 | 0C0C | distance=Distance{length=9576, | 100 | 1B06 | distance=Distance{length=12286, | 100}
1607979 | 0xâ€¦5106 location data | position |  | 2166 | 718 | -110 | 33 | distances |  | 5486 | distance=Distance{length=3475, | 100 | 8397 | distance=Distance{length=7968, | 100 | 0C0C | distance=Distance{length=9881, | 100 | 1B06 | distance=Distance{length=11953, | 100}
1607998 | 0xâ€¦4583 location data | position |  | 1673 | 825 | 217 | 30 | distances |  | 5486 | distance=Distance{length=2979, | 100 | 8397 | distance=Distance{length=8376, | 100 | 0C0C | distance=Distance{length=9599, | 100 | 1B06 | distance=Distance{length=12286, | 100}
1608080 | 0xâ€¦5106 location data | position |  | 2177 | 727 | -104 | 33 | distances |  | 5486 | distance=Distance{length=3485, | 100 | 8397 | distance=Distance{length=7959, | 100 | 0C0C | distance=Distance{length=9853, | 100 | 1B06 | distance=Distance{length=11906, | 100}
1608081 | 0xâ€¦4583 location data | position |  | 1676 | 819 | 188 | 27 | distances |  | 5486 | distance=Distance{length=3021, | 100 | 8397 | distance=Distance{length=8437, | 100 | 0C0C | distance=Distance{length=9646, | 100 | 1B06 | distance=Distance{length=12276, | 100}
1608181 | 0xâ€¦5106 location data | position |  | 2165 | 725 | -116 | 30 | distances |  | 5486 | distance=Distance{length=3475, | 100 | 8397 | distance=Distance{length=8053, | 100 | 0C0C | distance=Distance{length=9881, | 100 | 1B06 | distance=Distance{length=11864, | 100}
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

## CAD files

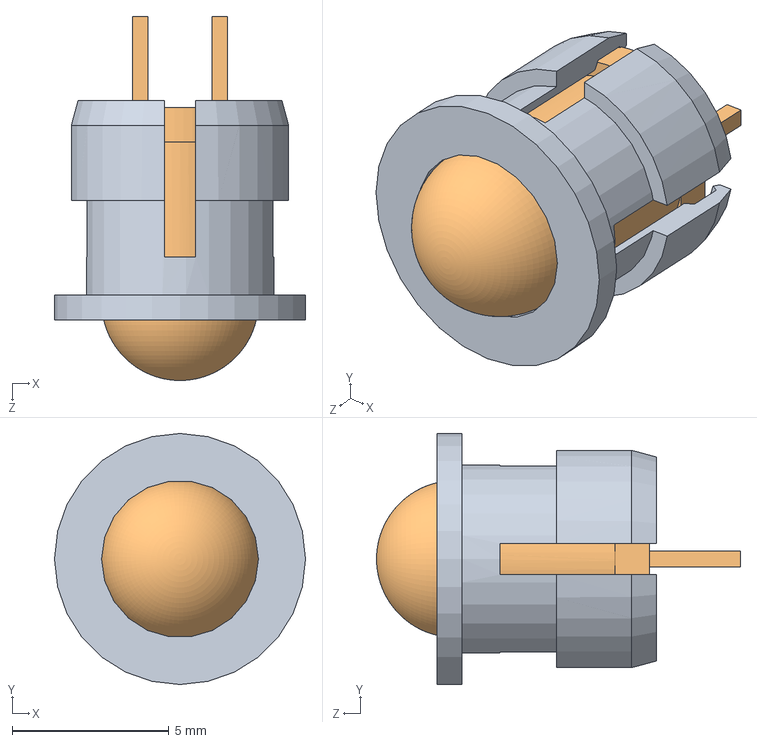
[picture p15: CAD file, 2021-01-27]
PhysicalSystem/3D_Models/Downloaded/5mm-led-grommit-1.snapshot.1/5mm-grommit-with-LED.SLDASM
8.00 x 8.00 x 11.6 mm
5mm LED GROMMIT
Led Lamp 5 mm

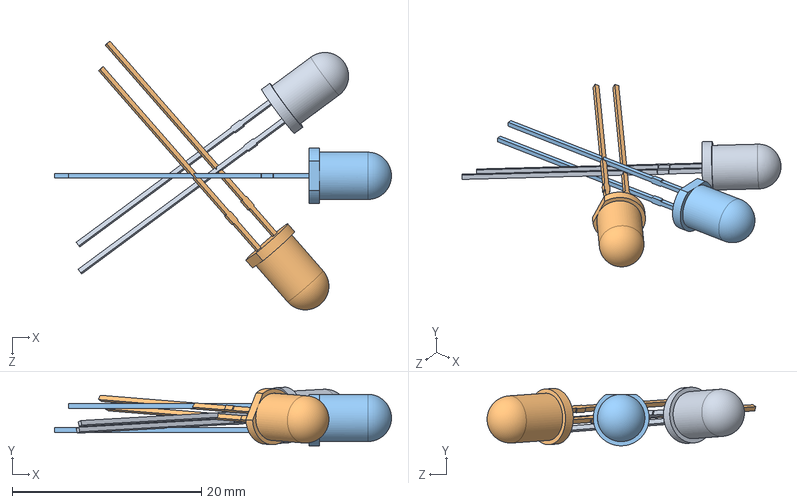
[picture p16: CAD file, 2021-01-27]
PhysicalSystem/3D_Models/Downloaded/led-5mm-2.snapshot.16/SolidWorks Çizimleri/Led Montaj.SLDASM
35.6 x 6.19 x 28.4 mm
Led Lamp 5 mm 1(2)
Led Lamp 5 mm 2
Led Lamp 5 mm 3

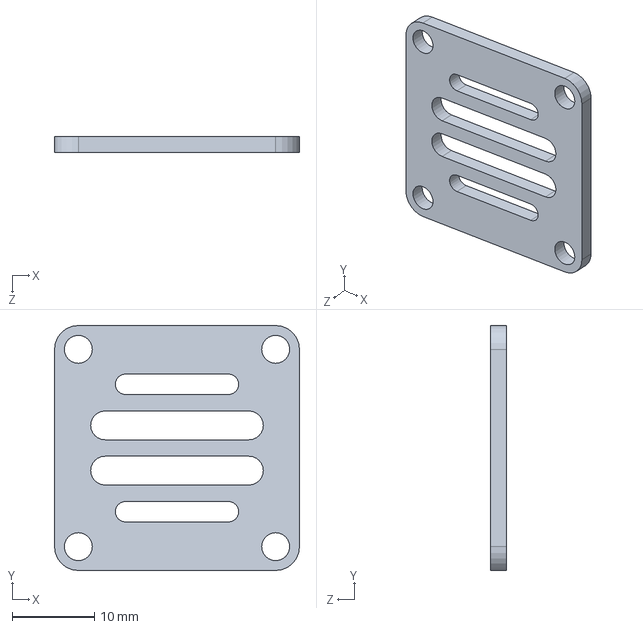
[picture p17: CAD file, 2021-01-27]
PhysicalSystem/3D_Models/CoLAB_Housing/Fan cover V2.SLDPRT
29.8 x 29.8 x 2.00 mm

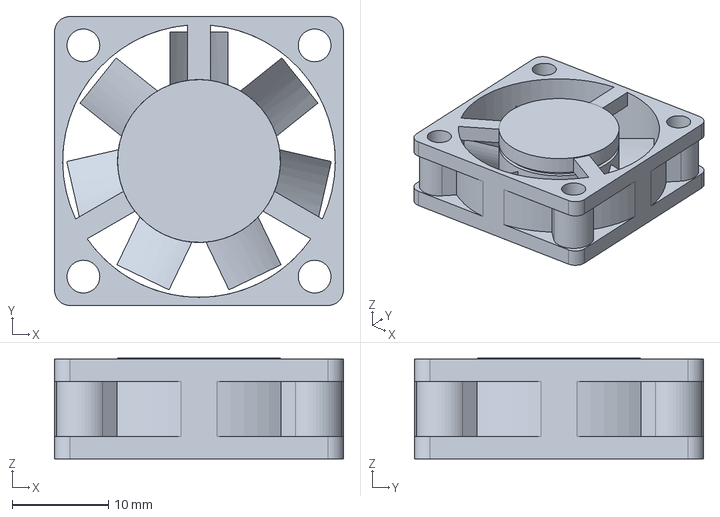
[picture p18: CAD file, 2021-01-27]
PhysicalSystem/3D_Models/Downloaded/30mm-dc-fan-1.snapshot.6/30X30X10 DC fan .step
30.0 x 30.0 x 10.4 mm

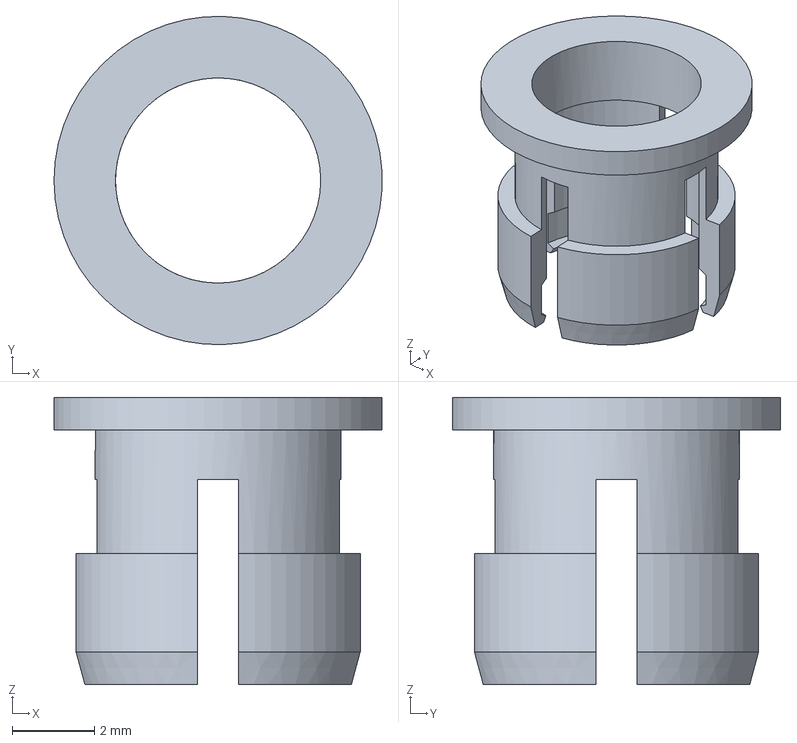
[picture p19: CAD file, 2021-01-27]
PhysicalSystem/3D_Models/Downloaded/5mm-led-grommit-1.snapshot.1/5mm LED GROMMIT.stp
7.99 x 8.00 x 7.00 mm

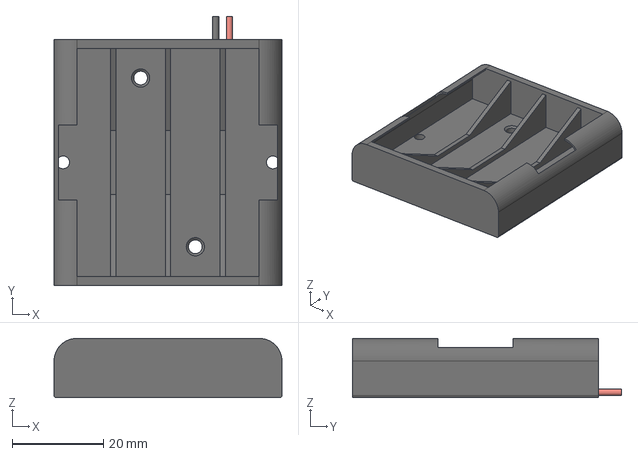
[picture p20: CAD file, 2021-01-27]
PhysicalSystem/3D_Models/Downloaded/AAA battery holder/AAA-battery-x4-case.step
50.0 x 59.0 x 13.0 mm

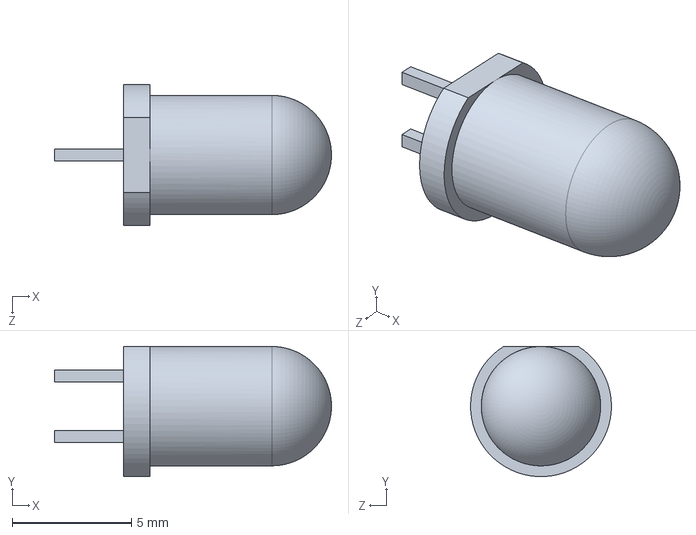
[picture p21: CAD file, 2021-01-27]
PhysicalSystem/3D_Models/Downloaded/led-5mm-2.snapshot.16/Led Lamp 5 mm.SLDPRT
11.6 x 5.45 x 5.90 mm

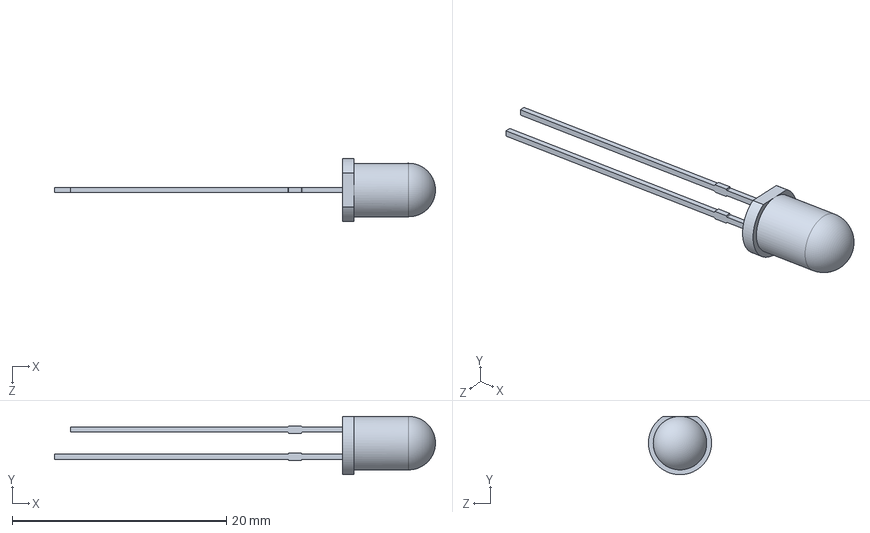
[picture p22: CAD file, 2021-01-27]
PhysicalSystem/3D_Models/Downloaded/led-5mm-2.snapshot.16/SolidWorks Çizimleri/Led Lamp 5 mm 1(2).SLDPRT
35.6 x 5.45 x 5.90 mm

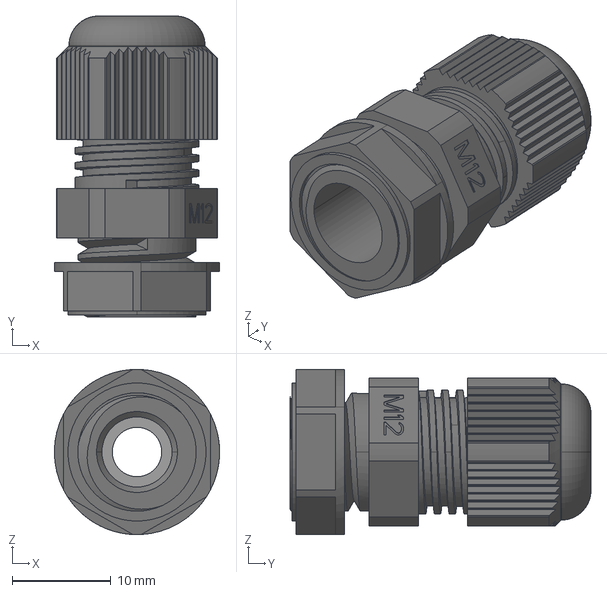
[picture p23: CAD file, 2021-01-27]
PhysicalSystem/3D_Models/Downloaded/m12-cable-gland-1.snapshot.1/gland_m12.stp
16.8 x 30.5 x 16.7 mm

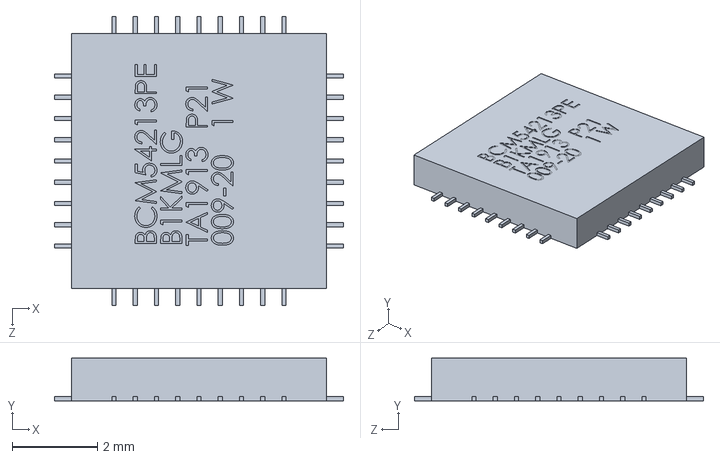
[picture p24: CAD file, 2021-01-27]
PhysicalSystem/3D_Models/Downloaded/raspberry-pi-4-model-b-1.snapshot.3/Broadcom BCM54213PE Gigabit Ethernet Transceiver, RPi4ModelB.SLDPRT
6.80 x 1.00 x 6.80 mm

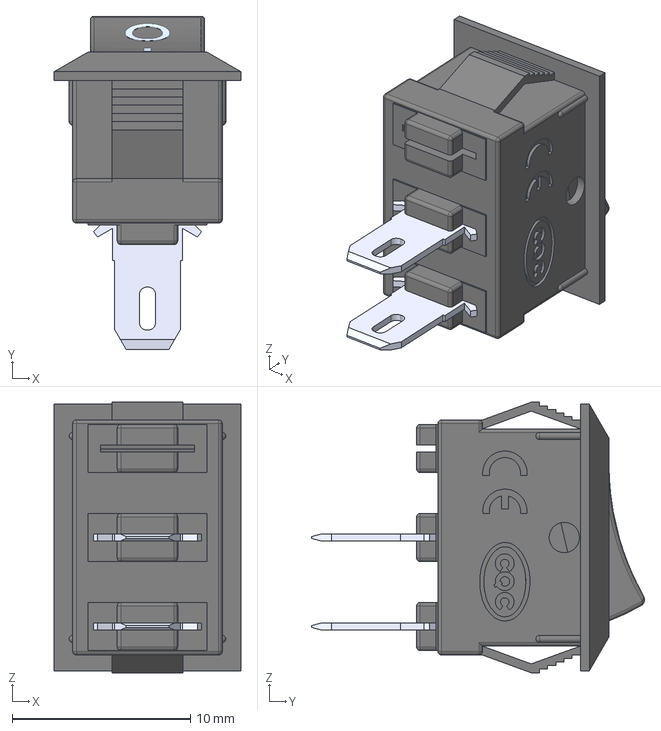
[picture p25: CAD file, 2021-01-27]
PhysicalSystem/3D_Models/Downloaded/small-power-switches-rocker-type-10-5x15mm-1.snapshot.7/KCD1-11-2P-On.step
10.5 x 18.7 x 15.2 mm

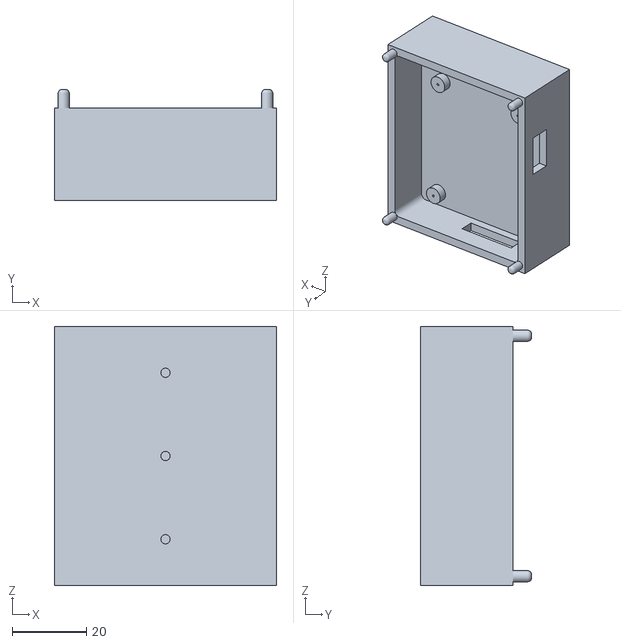
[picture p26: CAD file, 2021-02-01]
PhysicalSystem/3D_Models/Tag_Holder/STLs/Tag Holder Bottom (1).STL
60.0 x 30.0 x 70.0

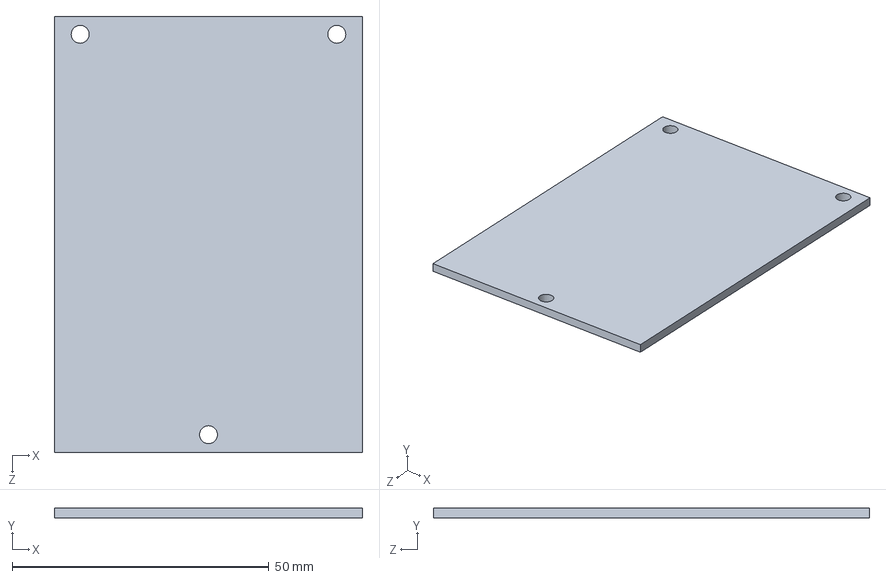
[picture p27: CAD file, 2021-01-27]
PhysicalSystem/3D_Models/CoLAB_Housing/Placeholder PCB V2.SLDPRT
60.0 x 2.00 x 85.0 mm

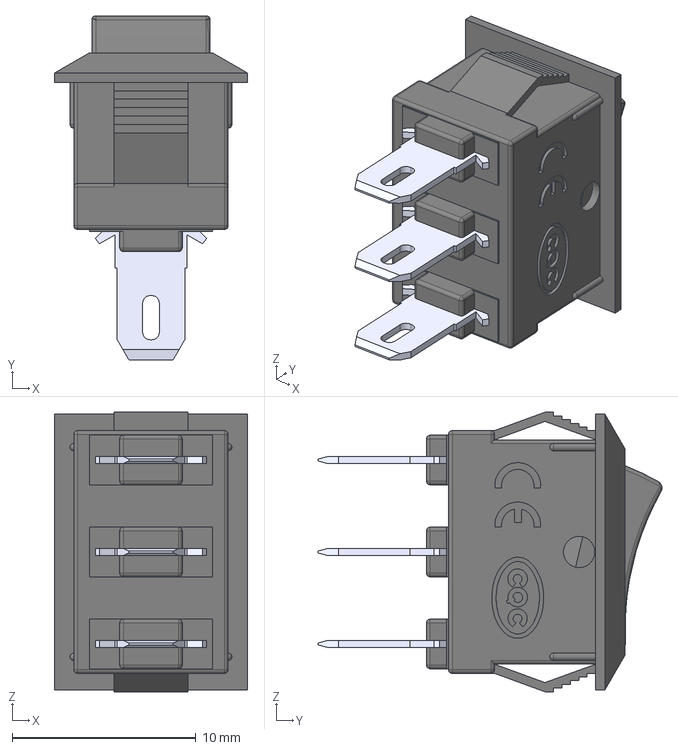
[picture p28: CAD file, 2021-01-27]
PhysicalSystem/3D_Models/Downloaded/small-power-switches-rocker-type-10-5x15mm-1.snapshot.7/KCD1-11-3P-Off.step
10.5 x 18.7 x 15.2 mm

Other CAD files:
PhysicalSystem/3D_Models/Tag_Holder/Tag Holder Bottom.SLDPRT
PhysicalSystem/3D_Models/Tag_Holder/STLs/Tag Holder Top Part (1).STL
PhysicalSystem/3D_Models/CoLAB_Housing/CoLAB Case Top V2.SLDPRT
PhysicalSystem/3D_Models/CoLAB_Housing/CoLAB Case V2.SLDPRT
PhysicalSystem/3D_Models/CoLAB_Housing/STL/CoLAB Case Top V2.STL
PhysicalSystem/3D_Models/CoLAB_Housing/STL/CoLAB Case V2.STL
PhysicalSystem/3D_Models/Downloaded/30mm-dc-fan-1.snapshot.6/30X30X10 DC fan.SLDPRT
PhysicalSystem/3D_Models/Downloaded/5mm-led-grommit-1.snapshot.1/5mm LED GROMMIT.SLDPRT
PhysicalSystem/3D_Models/Downloaded/AAA battery holder/AAA-battery-x4-case.SLDPRT
PhysicalSystem/3D_Models/Downloaded/AAA battery holder/AAA-battery-x4-case.f3d
PhysicalSystem/3D_Models/Downloaded/m12-cable-gland-1.snapshot.1/gland_m12.SLDPRT
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

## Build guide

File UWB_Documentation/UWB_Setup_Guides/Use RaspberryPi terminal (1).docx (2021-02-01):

UWB device:

The DecaWave UWB device provides a solution to real time localization system (RTLS) network. Many solutions had been done but not many would provide the localization across different AGVs platform. UWB technology has been in used since the 1960s and it provides a lower power spectral density of -40 dBm/MHz so as to avoid interference with other frequency like Wi-Fi or Bluetooth. The accuracy of the UWB technology is also high, error margin is within centimeters. The DecaWave UWB system consist of tags which are located on the AGVs, and anchor nodes which are placed around the needed workspace. In order to setup a network, there are two possibilities: creating the network through DRTLS app from DecaWave or through the serial communication. Both are described in the DW1001-DEV board documentations [LINK].

The system uses the Two-Way Ranging method to communicate. This method works similarly to a ping system as seen in figure below. Each message the tag send is included with a time stamp. The tag transmits a poll with its identifier to the anchor. Once a response from the anchor is received, the tag will send a final response with all related time stamps. By determining the time it takes for a signal to finish around trip, the distance between them can be calculated as follows:

ToF = ((TRR− TSP) − ( TSR−TRP) + ( TRF−TSR) − ( TSF−TRR))/ 4

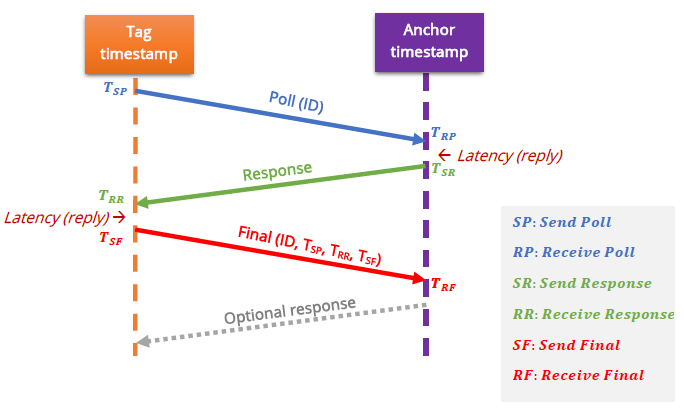
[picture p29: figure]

To determine the location of a UWB tag, the trilateration method was used. This method can be understood with the figure below. This method then find the intersecting point of 3 circles with the distance of each anchor to the tag as the radius of the respected circle. Because of this, the tag needs to send out polls to a minimum of 3 anchor nodes. By getting the distance between the tag and the anchor nodes, the UWB device would process the information into localization data using this formula:

(x_i -x)^2 +(y_i -y)^2 =r_i ^2

Where x_i and y_i are the coordinates of anchor number i, x and y are the coordinates of the tag.

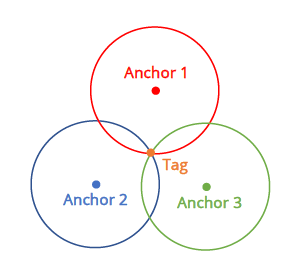
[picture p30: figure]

UWB possibilities: what functionality of the UWB can be useful

With the location data from the DecaWave UWB, there are many functionalities that can be infer. First and foremost, with these data, the system can have an overview of where different AGVs are and what is in their respective vicinity. This is achieved by finding the difference in coordinate of the tags. A visualization of this functionality is seen below.

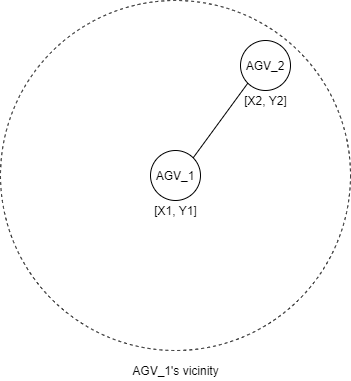
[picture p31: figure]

Although some AGVs do have the capability to see their respective speed, not all AGV have this feature. By observing how long it takes to reach from one data point to another, there is the possibility of measuring the speed of the AGV.

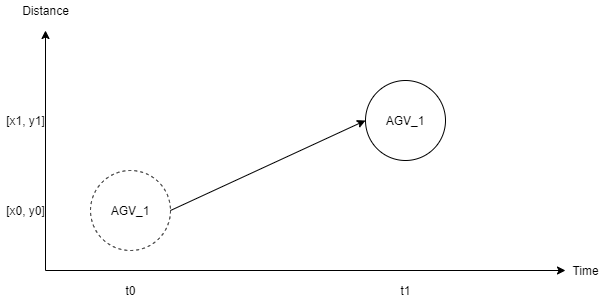
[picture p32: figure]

To find the orientation of the AGV, two tags will be used with each place at either the front or the rear of the AGV. Then by using the arc-tangent rule, the system can formulate the angle of the AGV comparing to the grid of anchors.

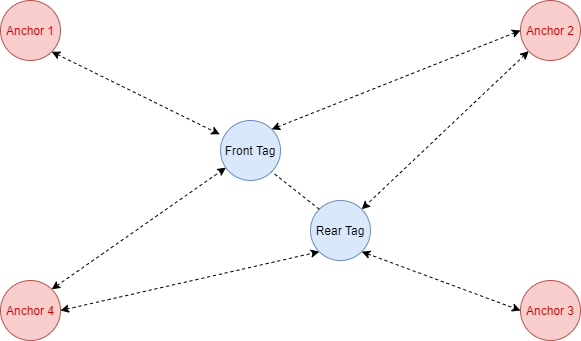
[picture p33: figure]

UART serial codes:

There are many options to access the UWB device for location data. The two communication protocols that was explored are UART serial and SPI. The advantage and disadvantages of both protocols will be discussed below.

SPI is the first type of communication protocol that was researched. The data flow of SPI is continuous as there is no start or stop bit. This could be seen as both good and bad impact. SPI boast a faster speed for communication messages thanks to the continuous flow. But since there is no stop bit, no acknowledgement could be confirmed which mean data could be lost without the knowledge of the system. As there are separate MISO and MOSI line, data can be transfer and receive at the same time. However, SPI requires a dedicated UWB device, besides the two tags, acting as a listener to be able to receive location information. This listener could lead to interference. Although this have not been tested but if two tags are placed within 15 centimetres of each other, the error margin is more significant. Also, since there is no parity bit, SPI cannot error check messages its receiving.

UART serial is the second choice and the communication protocol that was used in this project. UART is simpler to operate than SPI as it uses USB connection to communicate. One drawback of UART is the message size, a maximum of only 9 bits of data. Because the data require a stop bit from 9 bits of data, transfer rate is limited. But with the stop bit, the system can acknowledge if the data arrives correctly. Also, by using parity bit, the system can error check messages before receiving.

For the connection between the CoLAB’s raspberry pi and the UWB chip, UART serial was the chosen protocol. No extra listener is required. Since the location data transferred is small, UART 9-bits data size is more than sufficient to send. As the two tags requires power through USB, combining power and communication is also a reason to choose UART.

Explanation of UART serial code

The code below is within the config of the main sendLocation function and is used to set up serial config for both tags such as the correct baud rate that the UWB chip uses. The code also set up the size of the message with eight bits of data and one stop bit. Next, in order to access the UWB’s UART API through serial, a double-tapping of the enter key is needed to. With this, all necessary configuration for serial read to receive information is done.

#Front tag serial config

serFront = serial.Serial()

serFront.port = '/dev/UWBfront'

serFront.baudrate = 115200

serFront.bytesize = serial.EIGHTBITS

serFront.parity =serial.PARITY_NONE

serFront.stopbits = serial.STOPBITS_ONE

serFront.timeout = 1

serFront.open()

serFront.write(b'\r\r')

time.sleep(1)

serFront.close()

Within the main sendLocation function, for serial reading, the code will utilize the command “apg” from the DecaWave UWB. This command, when used, returns the location value based on the trilateration method used by DecaWave UWB. The message format is: “apg: x:### y:### z:### qf:###”. Once the message is returned, the code will read the data from the serial ports and pre-process it by removing unnecessary characters. Then the data will be saved globally within the function as a float array. The information within the array will be append to variables for further processing. The code below is an example for the front tag only.

# use “apg” command and read location data from UWB Front tag

serFront.write(b'apg\n')

serFront.readline()

dataFront = str(serFront.readline())

# pre-process location data to create array

dataFront = dataFront.split(' ')

dataFront[1] = float(dataFront[1].replace("x:",""))

dataFront[2] = float(dataFront[2].replace("y:",""))

dataFront[3] = float(dataFront[3].replace("z:",""))

dataFront[4] = dataFront[4].replace("qf:","")

dataFront[4] = float(dataFront[4].replace("\\r\\n'",""))

dataFront.pop(0)

# save data from location array for further processing

FTagX.append(dataFront[0])

FTagY.append(dataFront[1])

How to setup UART serial for the Raspberry Pi:

Setup the network with the app (Reminder: change stationary refresh rate to 10 Hz) [LINK]

Use RaspberryPi terminal to run these commands:

Command: dmesg | grep ttyUSB

to get serial number for individual UWB tags

first connect first tag to be the front tag.

>> Check first serial number

Then connect second tag to be the rear tag

>> Check second serial number

Command: sudo nano /etc/udev/rules.d/10-usb-serial.rules

to setup rules for later uses of the UWB

>> By using the command, a rules.d file will be created

>> Type these lines below and change the serial attribute with the serial number from above

SUBSYSTEM==”tty”, ATTRS{serial}==”############”, SYMLINK+=”UWBfront”

SUBSYSTEM==”tty”, ATTRS{serial}==”############”, SYMLINK+=”UWBrear”

ALL FILE RELATED NEEDS TO BE IN ONE FOLDER

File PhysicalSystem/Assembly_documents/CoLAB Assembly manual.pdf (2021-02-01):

# COLAB ASSEMBLY MANUAL

No. | Date of Chan g e | Notes
1. 01 | -02 -202 1 | Complete d the first manual draft

Note: This manual is made with the intent for advance user (such as technical students, teachers, and engineers), therefore cable and circuit connection will not be shown in here.

### Parts Description

The figures below show the complete look of the CoLAB housing (the lead and the bottom part) with the components.

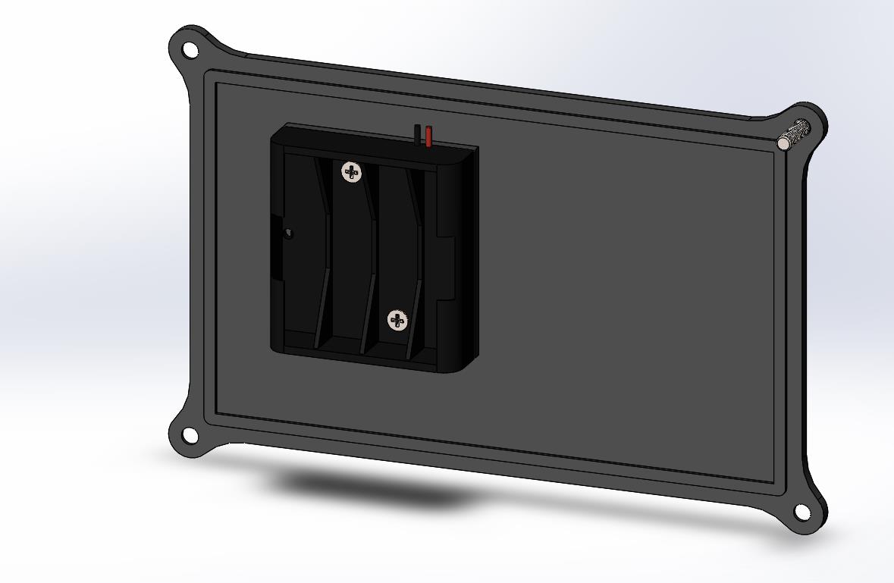
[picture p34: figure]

Figure 1: The top of The CoLAB housing

In the top part the only component that are placed there is the battery holder, while the rest of the component will be placed in the main part or the bottom part. As shown in the figure below.

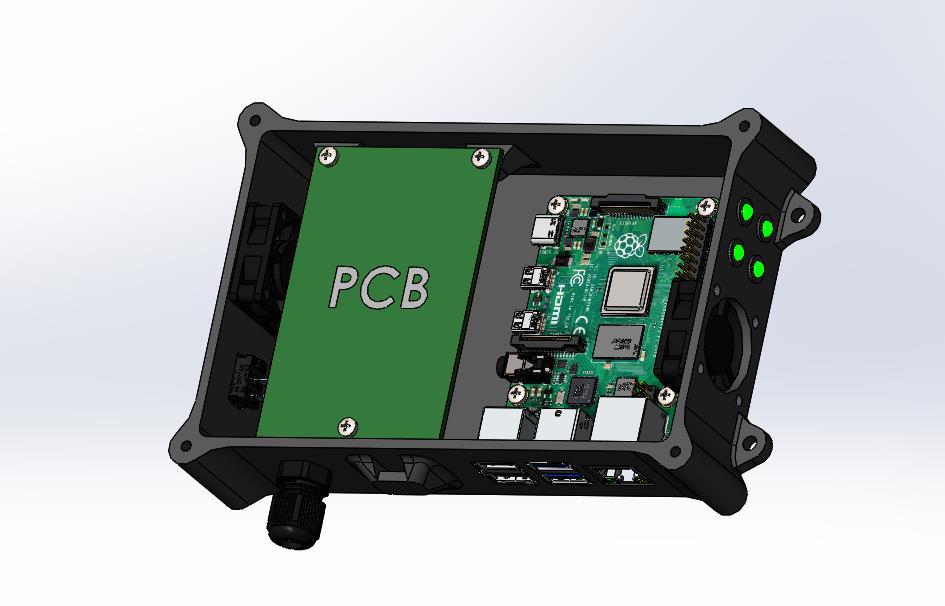
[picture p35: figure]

Figure 2: The bottom of the CoLAB housing

### Step 1 Switch installation

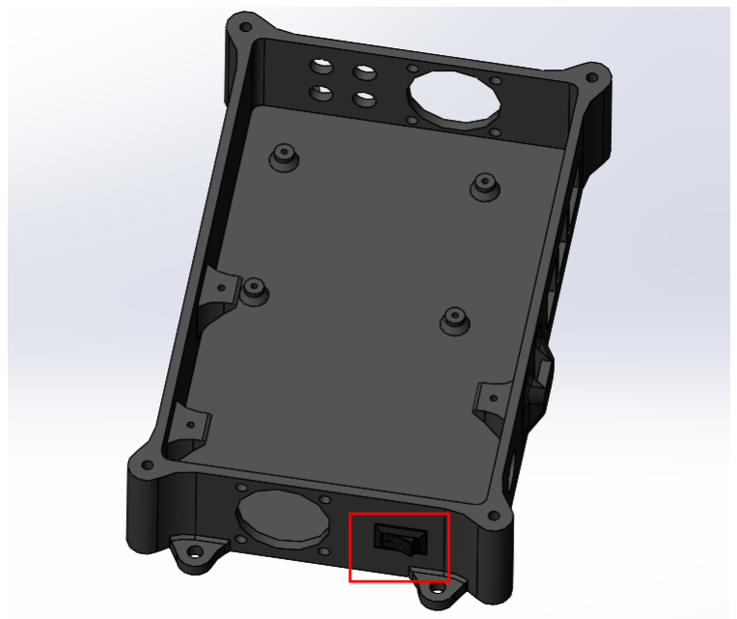
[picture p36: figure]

Figure 3: The first step of the assembly

The first step of the assembly, the rocker switch will be placed to the switch holder in the left side of the CoLAB housing, the indication for making sure it fits in is to put pressure the rocker switch until a “click” sound is heard.

### Step 2 Cable gland installation

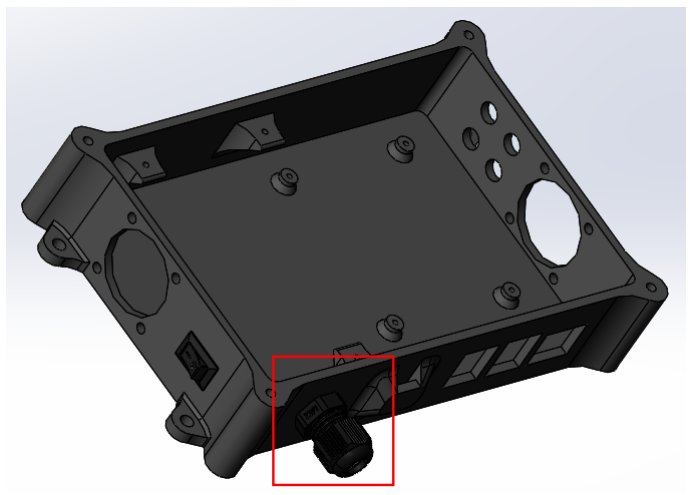
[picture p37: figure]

Figure 4: The second step of the assembly

Second, the Cable gland will be placed in bottom part of the Colab housing as highlighted in the figure above. To do this, the back part of the cable Gland needs to be unscrewed first, then after it has been mounted, screw back the back part to hold the cable firms to the CoLAB housing.

### Step 3 LED installation

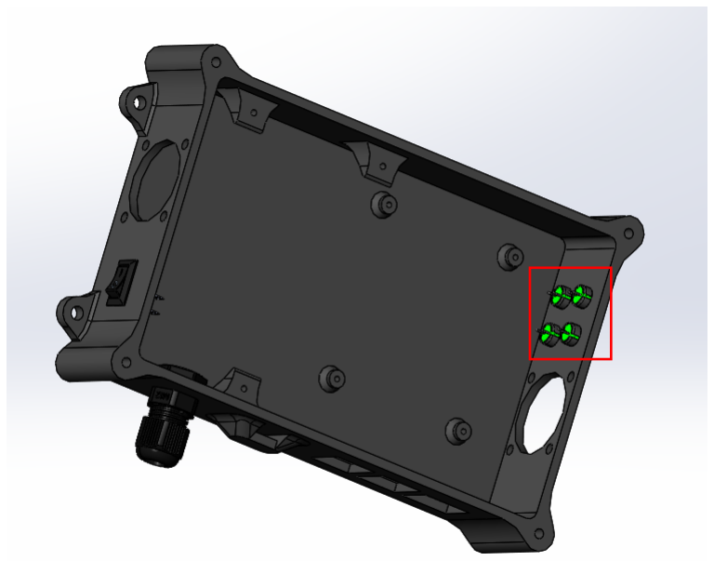
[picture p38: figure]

Figure 5: The third step of the assembly

In this part, because all the LED holders already fit in placed with the housing. The LED can be slide into the holder directly until it produced a “click” sound and the LED could no longer be moved.

### Step 4 Fan Installation

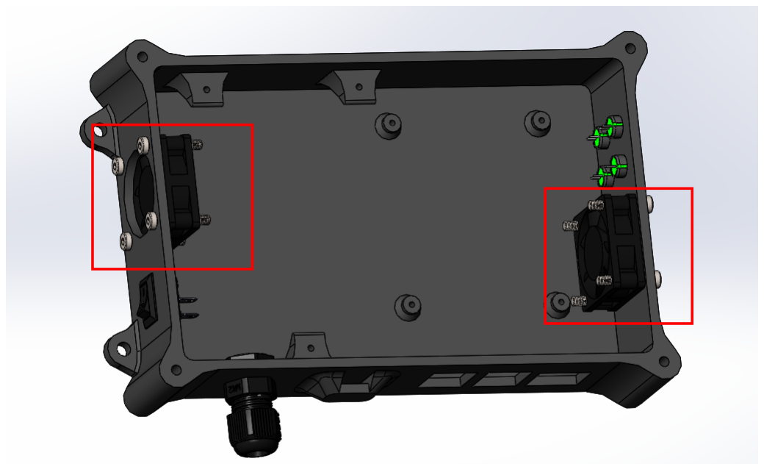
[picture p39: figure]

Figure 6: The fourth step of the assembly (from left side)

Next is to install the Fan to the housing, this can be done by placing one fan to the hole besides the LED while the other one to the hole beside the switch.

### Step 5 Housing the Raspberry Pi

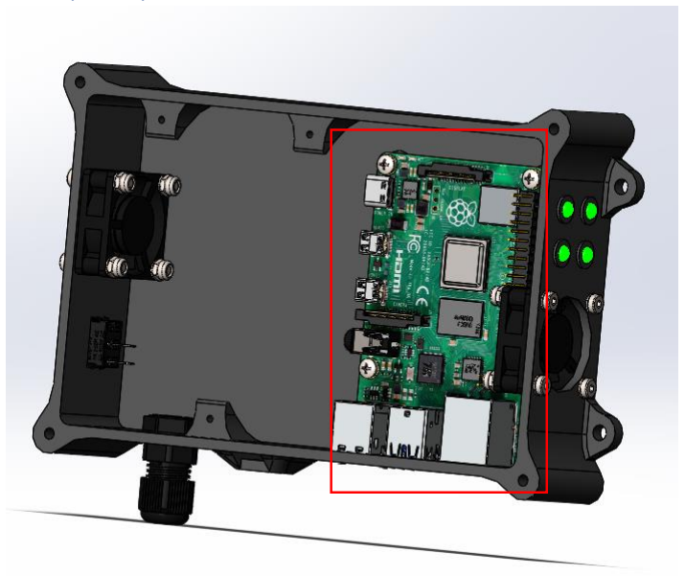
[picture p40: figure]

Figure 7: The fifth step of the assembly (from right side)

To house the Raspberry Pi the output ports need to be aligned with the CoLAB housing output socked first. After it fits, it can be screwed to the housing. Note, all necessary cable input such ass LED and fan needs to be connected first before the next part to avoid circuit malfunction.

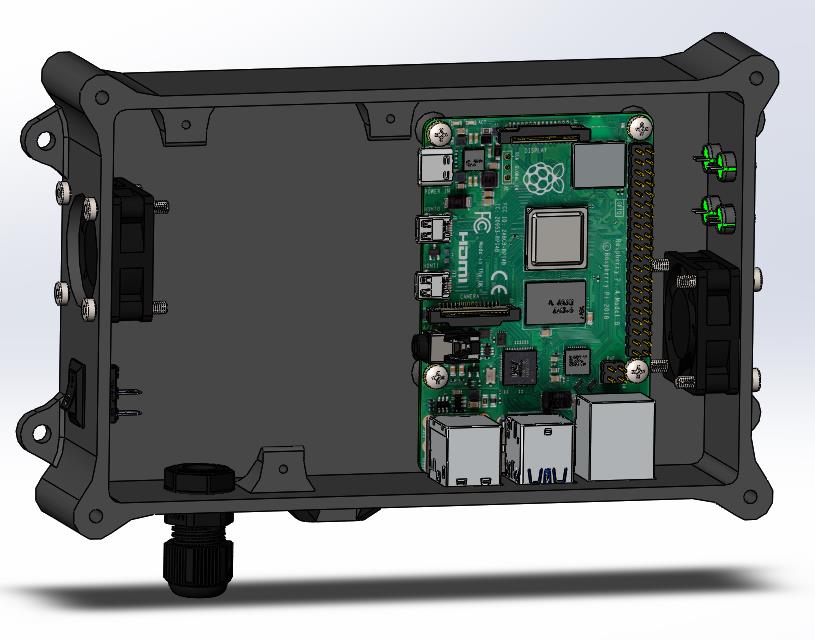
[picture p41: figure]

Figure 8: The Fifth step of the assembly (from left side)

### Step 6 Housing the PCB

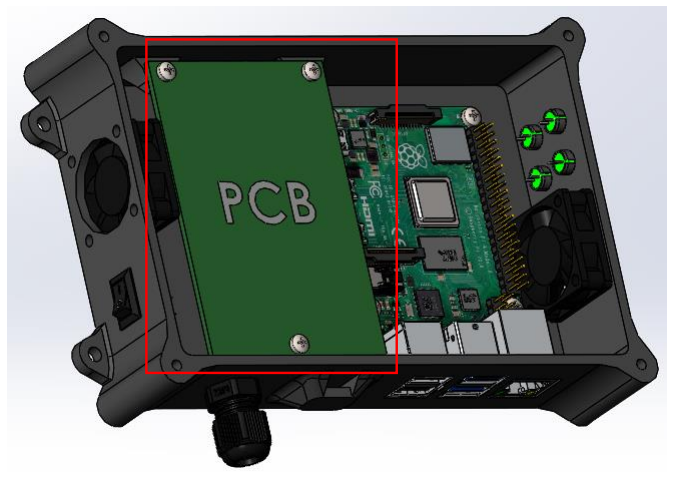
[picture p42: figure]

Figure 9: The sixth of the assembly

The last part before closing the CoLAB, the PCB will be installed upside down, the reason for this is to prevent the misfit with the top part of the CoLAB housing. For the placement direction, the top part will have 2 terminal block siding towards the raspberry Pi.

### Step 7 Finishing up

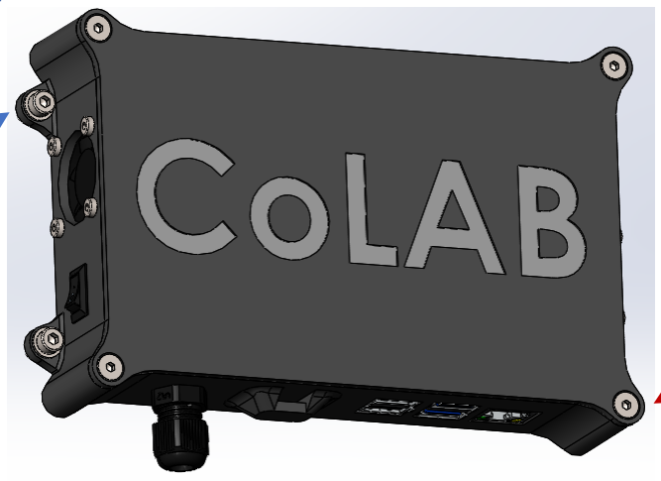
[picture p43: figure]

Figure 10: The complete CoLAB housing

Lastly, close the top part shut to the bottom, make sure the battery holder is located above the Raspberry Pi otherwise it won’t fit.

The screw for
attaching the CoLAB
housing to the AGV

The screw for attaching
the lead of the CoLAB
housing to the Bottom
part .

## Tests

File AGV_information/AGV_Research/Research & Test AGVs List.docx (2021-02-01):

# Research & Test AGVs

The team created a list of AGVs to research common AGV hardware and software. This list has been compiled after online research into AGV manufacturers and their products. Most of the AGVs on the list are part of the subcategory AMRs (Autonomous Mobile Robots) and are rated for a payload around 100kg. The Omron LD-60 and the MiR100 are the main test AMRs because these are available at Fontys. The other robots will serve as guidelines for design choices of the CoLAB.

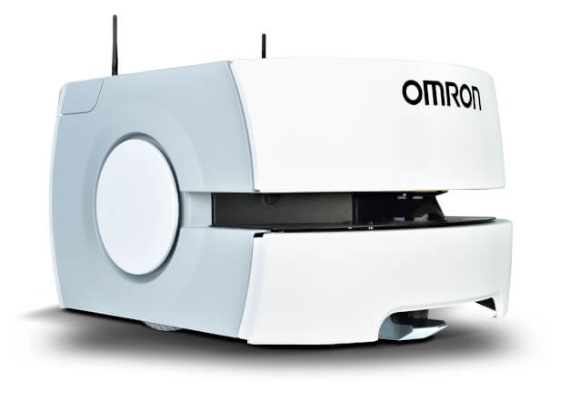
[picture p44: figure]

Omron, LD-60

https://industrial.omron.eu/en/products/ld-60-90

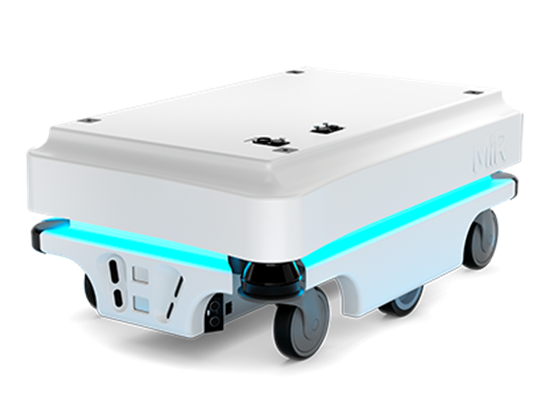
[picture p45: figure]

MiR, 100

https://www.mobile-industrial-robots.com/en/solutions/robots/mir100/

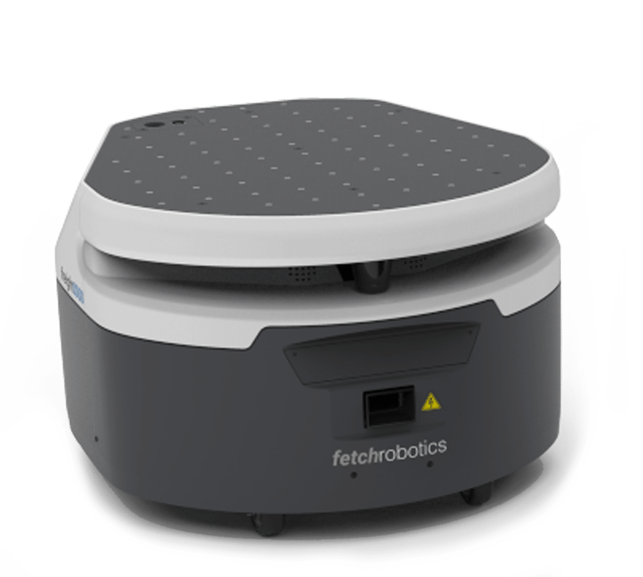
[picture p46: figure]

Fetch Robotics, Freight Base

https://fetchrobotics.com/robotics-platforms/freight-base/

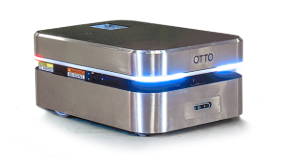
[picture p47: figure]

# Otto Motors, OTTO 100

https://ottomotors.com/amrs

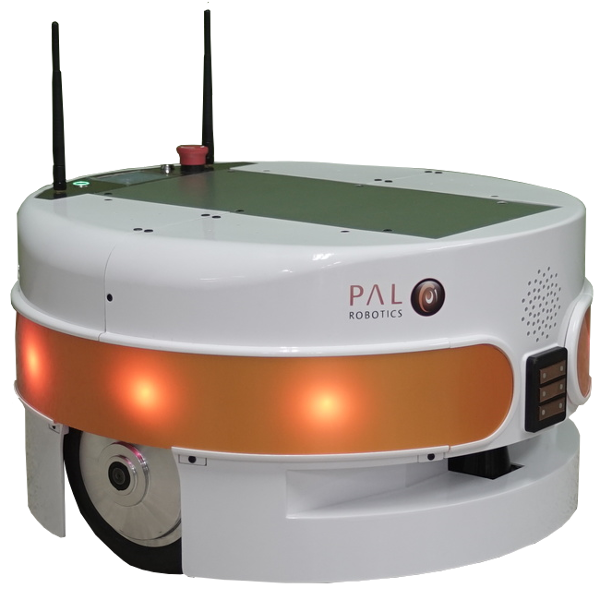
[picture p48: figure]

PAL Robotics, Tiago Base

https://pal-robotics.com/robots/tiago-base/

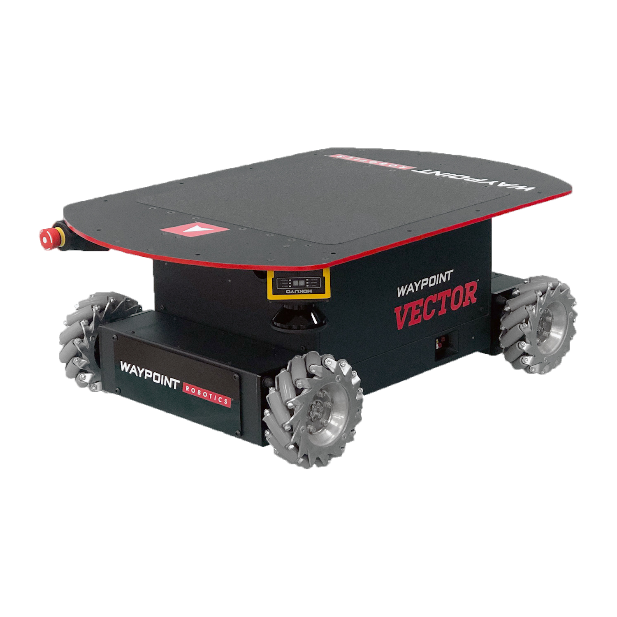
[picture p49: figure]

Waypoint Robotics, Vector™

https://waypointrobotics.com/
vector-robotic-mobility-platform/ (https://waypointrobotics.com/vector-robotic-mobility-platform/)


Clearpath, DINGO

https://clearpathrobotics.com/dingo-indoor-mobile-robot/


Geek+, M100

https://www.geekplus.com/product-2/moving

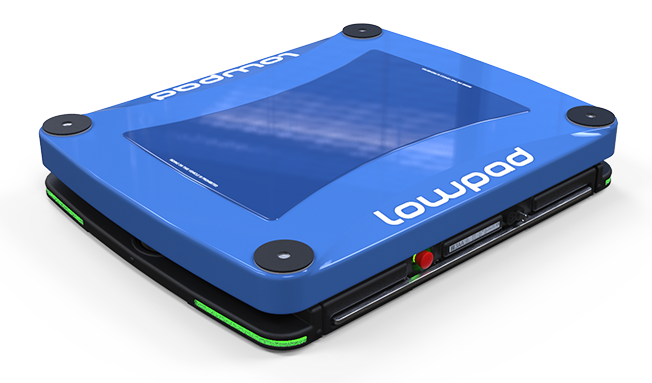
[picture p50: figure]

Lowpad, M

https://www.lowpad.com/lowpad-family/lowpad-m

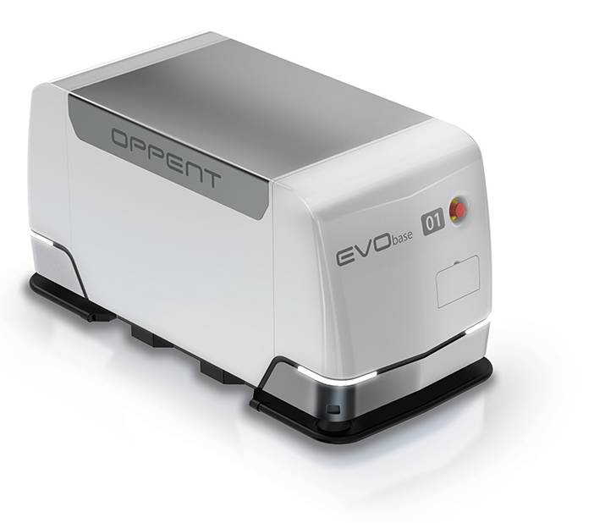
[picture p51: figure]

Oppent EVO, base™

https://www.oppent-evo.com/en/prodotto/evo-base-2/

https://www.ifollow.fr/produits/

Some other market leading AGV companies:

- Swisslog
- Locus
- Amazon

These companies deliver complete AGV solutions with their own infrastructure.

# Resources used for creating the Research & Test AGVs list

https://www.robotics.org/blog-article.cfm/Autonomous-Mobile-Robots-The-Latest-Applications-and-Use-Cases-from-Leading-Suppliers-and-Users/266

https://www.openpr.com/news/1790541/autonomous-mobile-robots-market-expected-to-thrive-at-impressive-cagr-during-the-period-2023-swisslog-kuka-omron-adept-clearpath-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

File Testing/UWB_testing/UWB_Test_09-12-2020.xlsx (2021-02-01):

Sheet: MiRTest2Cross
Time stamp (Measured) [s] | Time stamp [s] | X- Front [mm] | Y-Front [mm] | X-Rear [mm] | Y-Rear [mm] | Z-Front [mm] | Z-Rear [mm] | Q-Front | Q-Rear | Initial Time Stamp | Distance between Tags [mm] | Measured Distance between Tags [mm] |  |  | X-front | Y-front | X-rear | Y-rear | Z diff
1898.176 | 0.00 | 2317 | 4829 | 1974 | 5009 | 534 | 392 | 72 | 67 | 1898.176 | 654 | 387.36 | 854 | 454 | 2344 | 4841.555556 | 1946.222222 | 5012.888889 | 142
1898.276 | 0.10 | 2319 | 4830 | 1947 | 5003 | 531 | 440 | 70 | 66 |  | 654 | 410.26 | 854 | 454 | 2402.666667 | 4825 | 1970 | 4993 | 91
1898.376 | 0.20 | 2316 | 4834 | 1957 | 5001 | 532 | 456 | 70 | 67 |  | 654 | 395.94 | 854 | 454 | 2555.333333 | 4783.111111 | 2097.222222 | 4934 | 76
1898.476 | 0.30 | 2341 | 4839 | 1953 | 4998 | 527 | 463 | 71 | 66 |  | 654 | 419.31 | 854 | 454 | 2692.222222 | 4732.666667 | 2224.555556 | 4820.888889 | 64
1898.576 | 0.40 | 2361 | 4853 | 1963 | 5012 | 580 | 478 | 74 | 67 |  | 654 | 428.58 | 854 | 454 | 2856.555556 | 4722.222222 | 2444.111111 | 4856.555556 | 102
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

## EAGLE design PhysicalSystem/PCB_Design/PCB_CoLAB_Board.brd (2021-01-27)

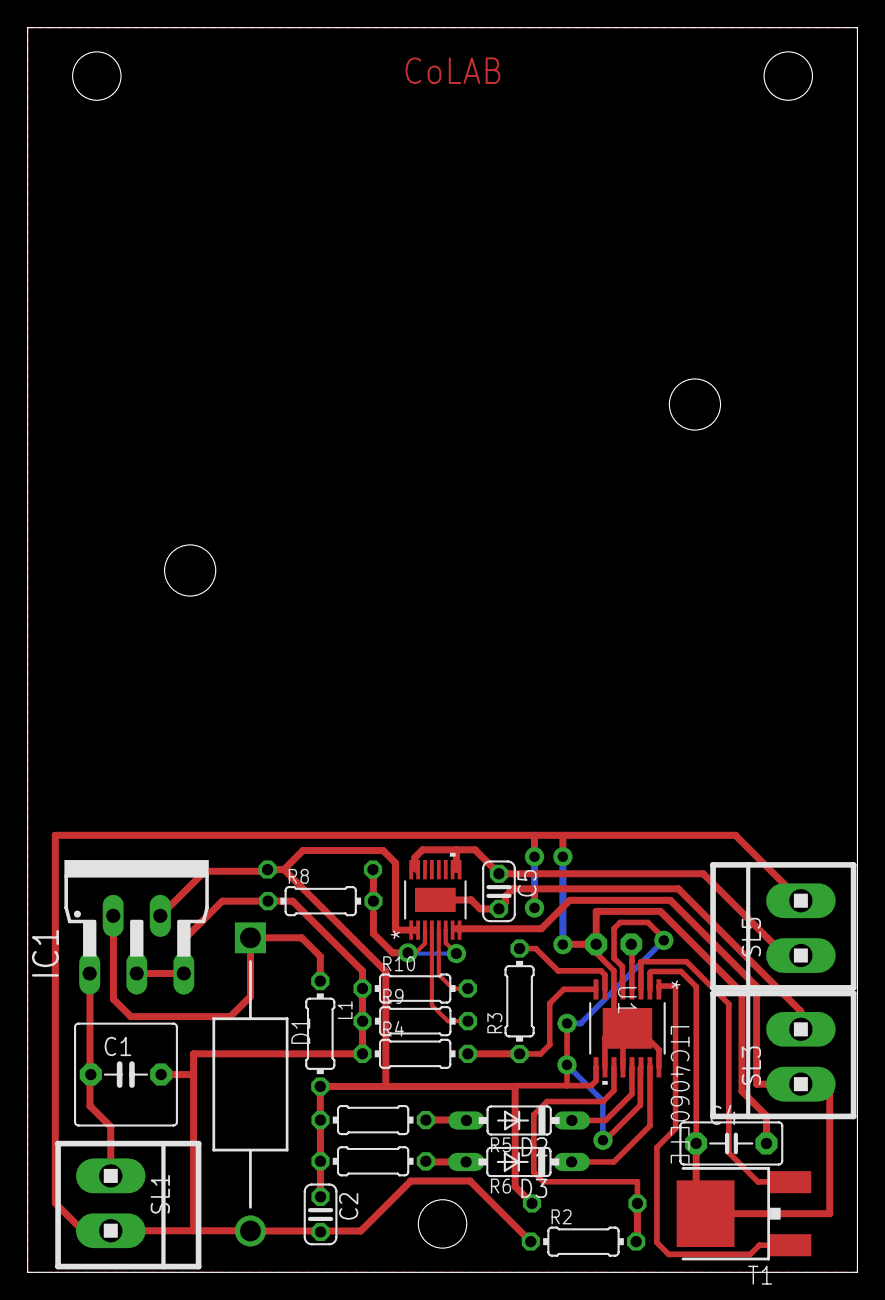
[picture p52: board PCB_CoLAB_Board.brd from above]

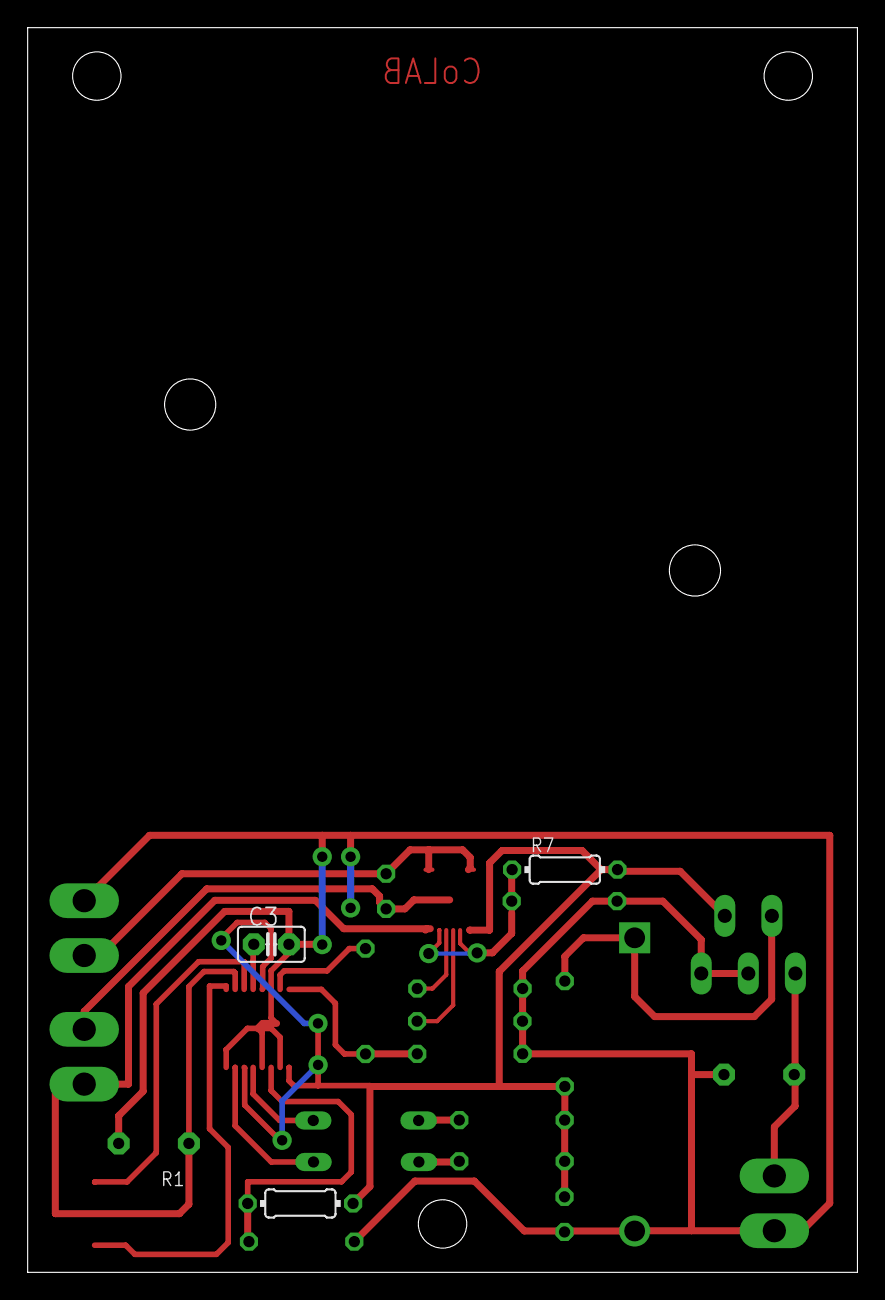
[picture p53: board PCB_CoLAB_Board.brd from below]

Board: 2 copper layers, 60.0 x 90.0 mm, 26 parts (3 on the bottom side), 18 nets.

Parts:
C1: C5B7.2
C2, C5: C025-024X044
C3: C2.5-2
C4: C5B3
D1: 1N5822; DIOAD2120W130L950D530P
D2, D3: 1N4148DO35-7; DO35-7
IC1: LM2596T; T05D
L1: 0204/7
R1, R2, R3, R4, R5, R6, R7, R8, R9, R10: 0204/7
SL1, SL3, SL5: 1X2MTA
T1: MJD32; DPAK
U1: LTC4060EFE; TSSOP-16_FE/BC_LIT
U2: LTC4415EMSEPBF; MSOP-16_MSE

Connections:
GND: C1.2, C2.2, C3.2, C4.2, C5.2, D1.A, IC1.3, IC1.5, R2.1, R4.1, R8.1, R9.1, R10.1, SL1.1, SL3.1, SL5.1, U1.6, U1.10, U1.12, U1.16, U1.EPAD, U2.17
unnamed: R3.2, U1.7
unnamed: C1.1, IC1.1, SL1.2
unnamed: D1.C, IC1.2, L1.1
unnamed: R1.1, R2.2, U1.11
unnamed: R7.1, R8.2, U2.3, U2.6
unnamed: R3.1, R4.2, U1.8
unnamed: T1.3, U1.3
unnamed: T1.1, U1.1
unnamed: C2.1, IC1.4, L1.2, R1.2, R5.2, R6.2, R7.2, U1.5, U1.9, U1.14, U2.1
unnamed: C3.1, U1.4
unnamed: D2.A, R5.1
unnamed: D2.C, U1.13
unnamed: D3.C, U1.15
unnamed: D3.A, R6.1
unnamed: C4.1, SL3.2, T1.4, U1.2, U2.7, U2.8
unnamed: R10.2, U2.5
unnamed: C5.1, SL5.2, U2.9, U2.10, U2.15, U2.16

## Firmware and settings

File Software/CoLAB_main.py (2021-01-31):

import paho.mqtt.client as mqtt
import paho.mqtt.publish as publish
import requests
import json
import time
import math

import CoLAB_sendLocation as sendLocation
import CoLAB_config as config
import CoLAB_restAPI_MiR as restAPI

# Activate/deactivate prints for debugging
debugPrints = True

# Global list with all AGVs within a set range
AGVMap = []
# Global list with all the open tasks responded to
taskList = []


# Handler for messages in the LOCATION topic
def locationHandler(msg):
    """Handler for messages in the LOCATION topic"""

    payloadReceived = json.loads(msg.payload)

    # check if the received location is not the location of this AGV
    if payloadReceived["colab_id"] != config.colab_id:
        global AGVMap
        # calculating the boundaries locations based on the current location of the AGV and the boundarie range
        boundRange = 100
        XBound = [sendLocation.preProcessedLocation[0] - boundRange, sendLocation.preProcessedLocation[0] + boundRange] #in meters
        YBound = [sendLocation.preProcessedLocation[1] - boundRange, sendLocation.preProcessedLocation[1] + boundRange]

        # variable to indicate if the AGV is already in the AGVMap
        AGVInList = False

        # check if the received AGV location is within the set boundaries from the AGV
        if XBound[0] <= payloadReceived["location"][0] <= XBound[1] and YBound[0] <= payloadReceived["location"][1] <= YBound[1]:
            # calculate the distance from this AGV to the received AGV location
            DistancetoAGV = math.sqrt(math.pow(payloadReceived["location"][0]- sendLocation.preProcessedLocation[0],2) + math.pow(payloadReceived["location"][1]- sendLocation.preProcessedLocation[1],2))

            # calculate the angle from this AGV to the received AGV location
            #AngletoAGV = math.atan2((payloadReceived["location"][1]- sendLocation.preProcessedLocation[1]),(payloadReceived["location"][0]- sendLocation.preProcessedLocation[0])) * 180/math.pi

            # store the CoLAB_ID together with the distance and angle to the AGV
            infoList = [payloadReceived["colab_id"], round(DistancetoAGV, 2), payloadReceived["location"], payloadReceived["orientation"]]

            # check if the AGV is already in the AGVMap
            for i in range(0, len(AGVMap)):
                if AGVMap[i][0] == infoList[0]:
                    # update the AGV information to the new information
                    AGVMap[i][1] = infoList[1]
                    AGVMap[i][2] = infoList[2]
                    AGVMap[i][3] = infoList[3]

                    # set AGVInList true to indicate that this AGV is already in the AGVMap
                    AGVInList = True

                    # exit the for loop if a match is found
                    break

            # if the AGV was not found in AGVMap then add it
            if AGVInList == False:
                AGVMap.append(infoList)

            # display the current AGVMap list
            if debugPrints == True: print('AGVs within', boundRange, 'meters:', AGVMap)

# Handler for messages in the TASKS topic
def tasksHandler(msg):
    """Handler for messages in the TASKS topic"""

    payloadReceived = json.loads(msg.payload)

    # when a new task is received in the tasks topic
    if payloadReceived["msg_type"] == "task":
        global taskList
        # print the task that is received with the task details
        if debugPrints == True: print('Task', payloadReceived["task_id"], 'received with details:', payloadReceived["details"])

        # --- calculation of the cost based on the task details and AGV specification/status ---

        # build the dictionary with the data to send
        message = {
            "msg_type": "response",
            "task_id": payloadReceived["task_id"],
            "sender": config.colab_id,
            "cost": config.cost
        }

        # add the new task to the task list
        taskList.append([message["task_id"], message["cost"]])

        # print the message to send
        if debugPrints == True: print('Responded to task: ', message["task_id"], '  with cost:', message["cost"], '\n')

        # create a string with the data in JSON format
        message = json.dumps(message)

        # publish the message in the messenger topic
        publish.single("CRL/tasks", message, hostname=config.mqttBroker)

    # when a response from a different CoLAB is received in the tasks topic
    if (payloadReceived["msg_type"] == "response") and (payloadReceived["sender"] != config.colab_id):
        
        for i in range(0, len(taskList)):
            if payloadReceived["task_id"] in taskList[i]:
                # check if the cost of the received response is lower then the cost in the task list of the CoLAB
                if payloadReceived["cost"] < taskList[i][1]:
                    # remove the task from the task list
                    taskList.pop(i)
                else:
                    # don't look through the rest of the task list if the task is found with a lower cost
                    break
    
    # when a task is open for accepting
    if payloadReceived["msg_type"] == "accept":
        # check if the task that is open to accept is in the task list
        for i in range(0, len(taskList)):
            if payloadReceived["task_id"] in taskList[i]:
                # print that this CoLAB has accepted the task
                if debugPrints == True: print('Task', payloadReceived["task_id"], 'Accepted', '\n')

                # build the dictionary with the data to send
                message = {
                    "msg_type": "accepted",
                    "task_id": payloadReceived["task_id"],
                    "sender": config.colab_id
                }
                # create a string with the data in JSON format
                message = json.dumps(message)

                # publish the message in the messenger topic
                publish.single("CRL/tasks", message, hostname=config.mqttBroker)

                # execute the task (for now a demo mission)
                if config.restAvailable == True:
                    restAPI.demoMisson()

                # remove the task from the task list
                taskList.pop(i)

                # exit the loop to stop checking the rest of the task list
                break

# Handler for messages in the MESSENGER topic
def messengerHandler(msg):
    """Handler for messages in the MESSENGER topic"""

    payloadReceived = json.loads(msg.payload)

    # check if message is for this CoLAB
    if (payloadReceived["receiver"] == config.colab_id) or (payloadReceived["receiver"] == "all"):
        # display the incoming message
        if debugPrints == True: print('Received: ', payloadReceived["message"], '  from', payloadReceived["sender"])

        # fixed test response if received message is "hello"
        if payloadReceived["message"] == "hello":

            # build the dictionary with the data to send
            message = {
              "receiver": payloadReceived["sender"],
              "message": "world",
              "sender": config.colab_id
            }

            # print the message to send
            if debugPrints == True: print('Send: ', message["message"], '  to', message["receiver"], '\n')

            # create a string with the data in JSON format
            message = json.dumps(message)

            # publish the message in the messenger topic
            publish.single("CRL/messenger", message, hostname=config.mqttBroker)
            

        # reply to getBattery with the battery percentage of the AGV
        if payloadReceived["message"] == "getBattery":
                
            # get the battery percentage of the AGV via RestAPI
            if config.restAvailable == True:
                batteryPercentage = restAPI.getBatteryPercentage()

                # build the dictionary with the data to send
                message = {
                  "receiver": payloadReceived["sender"],
                  "message": batteryPercentage,
                  "sender": config.colab_id
                }

                # print the message to send
                if debugPrints == True: print('Send: ', message["message"], '  to', message["receiver"], '\n')

                # create a string with the data in JSON format
                message = json.dumps(message)

                # publish the message in the messenger topic
                publish.single("CRL/messenger", message, hostname=config.mqttBroker)


# The callback for when the client receives a CONNACK response from the server.
def on_connect(client, userdata, flags, rc):
    """Callback for when the client receives a CONNACK response from the server"""

    if debugPrints == True: print("Connected with result code " + str(rc) + "\n")
 
    # Subscribing in on_connect() - if we lose the connection and
    # reconnect then subscriptions will be renewed.
    client.subscribe("CRL/location")
    client.subscribe("CRL/tasks")
    client.subscribe("CRL/messenger")

# The callback for when a PUBLISH message is received from the server.
def on_message(client, userdata, msg):
    """Callback for when a PUBLISH message is received from the server"""

    # when a message is received in the LOCATION topic 
    if msg.topic == "CRL/location":
        locationHandler(msg)

    # when a message is received in the BLACKBOARD topic 
    elif msg.topic == "CRL/tasks":
        tasksHandler(msg)

    # when a message is received in the MESSENGER topic 
    elif msg.topic == "CRL/messenger":
        messengerHandler(msg)

# Create an MQTT client, attach the custom routines to it and start it on a separete thread
def startMQTT():
    """Create a MQTT client, connect to the MQTT broker specified in CoLAB_config.py and start the client on a new thread"""

    client = mqtt.Client()
    client.on_connect = on_connect
    client.on_message = on_message

    if debugPrints == True: print("Connecting to MQTT Broker:", config.mqttBroker)

    client.connect(config.mqttBroker, 1883, 60)

    # start MQTT thread
    client.loop_start()


if debugPrints == True: print('CoLAB main code running (CoLAB ID:', config.colab_id, ")")

startMQTT()
#sendLocation.startSending()

#while True:
#    pass

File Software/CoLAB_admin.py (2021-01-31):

import paho.mqtt.client as mqtt
import paho.mqtt.publish as publish
import json
import time

mqttBroker = "test.mosquitto.org"

# The callback for when the client receives a CONNACK response from the server.
def on_connect(client, userdata, flags, rc):
    print("Connected with result code "+str(rc))
 
    # Subscribing in on_connect() - if we lose the connection and
    # reconnect then subscriptions will be renewed.
    client.subscribe("CRL/location")
    client.subscribe("CRL/tasks")
    client.subscribe("CRL/messenger")

# The callback for when a PUBLISH message is received from the server.
def on_message(client, userdata, msg):

    # when a message is received in the location topic 
    if msg.topic == "CRL/location":
        #payload = json.loads(msg.payload)
        #print(payload)
        pass

    # when a message is received in the blackboard topic 
    if msg.topic == "CRL/tasks":
        payload = json.loads(msg.payload)
        #print(payload)
        if payload["msg_type"] == "accepted":
            print(payload["sender"], 'accepted task', payload["task_id"])

    # when a message is received in the messenger topic 
    if msg.topic == "CRL/messenger":
        payload = json.loads(msg.payload)

        # check if message is for this CoLAB
        if payload["receiver"] == ("admin"):
            print('Received: ', payload["message"], '    from', payload["sender"])

# Create an MQTT client, attach the custom routines to it and start it on a separete thread
def startMQTT():                
    client = mqtt.Client()
    client.on_connect = on_connect
    client.on_message = on_message

    print("Connecting to MQTT Broker:", mqttBroker)

    client.connect(mqttBroker, 1883, 60)

    # start MQTT thread
    client.loop_start()
    time.sleep(1)

print("----------------------\n- ADMIN DEMO CONSOLE -\n----------------------")
startMQTT()

while True:
    inp = input("\nMessage (m) or Task (t)? ")
        
    if inp == "task" or inp == "Task" or inp == "t" or inp == "T":
        task_id = input("Task_id: ")
        action = input("send (s) or accept (a)? ")

        if action == "send" or action == "Send" or action == "s" or action == "S":
            data = {
              "msg_type": "task",
              "task_id": task_id,
              "details": {
                "pickLocation": [23.89, 12.69],
                "placeLocation": [4.23, 9.76],
                "payloadSize": [100, 200, 300],
                "payloadWeight": 43.8
                }
            }
            print('Published new task with Task_ID: ', data["task_id"])
            print('task detail: ', data["details"])

            data = json.dumps(data)
            publish.single("CRL/tasks", data, hostname=mqttBroker)

        elif action == "accept" or action == "Accept" or action == "a" or action == "A":
            data = {
              "msg_type": "accept",
              "task_id": task_id,
            }
            print('Task', data["task_id"], 'can be accepted by an AGV')

            data = json.dumps(data)
            publish.single("CRL/tasks", data, hostname=mqttBroker)
        
        else:
            print("error: invalid input")


    elif inp == "message" or inp == "Message" or inp == "m" or inp == "M":
        receiver = input("CoLAB ID of receiver (or all): ")
        message = input("Message: ")

        data = {
          "receiver": receiver,
          "message": message,
          "sender": "admin"
        }
        print('Send: ', data["message"], '    to', data["receiver"])

        data = json.dumps(data)
        publish.single("CRL/messenger", data, hostname=mqttBroker)
    
    else:
        print("error: invalid input")

    time.sleep(1)
